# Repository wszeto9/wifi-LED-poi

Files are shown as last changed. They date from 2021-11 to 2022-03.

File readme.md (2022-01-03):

# WiFi-LED-Poi
USB-C Rechargable, WiFi Capable Glow Poi

<h2> Features:</h2>
<ul>
<li>ESP-32 MCU capable of WiFi-communication and syncronization of lights with music</li>
<li>Rechargable battery with a battery life of 3.5-5 hours</li>
<li>Programmable over USB-C</li>
<li>Charging over USB-C</li>
<li>0.47F Supercapacitor capable of nefarious discharge acts</li>
<li>Onboard accelerometer and microphone</li>
</ul>

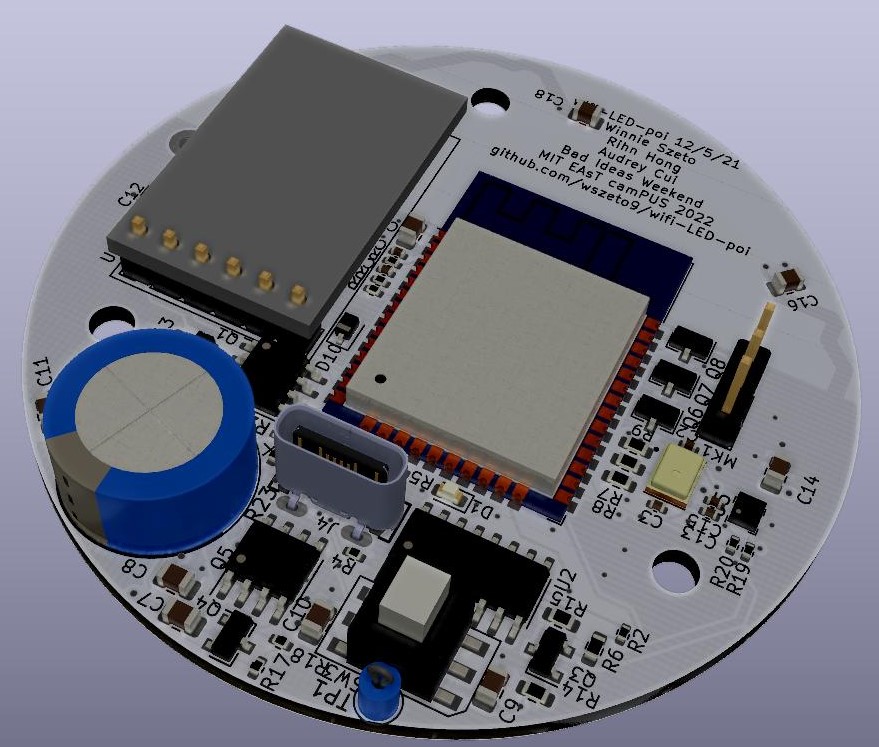
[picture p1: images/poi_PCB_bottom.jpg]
BOTTOM

PCB Bottom

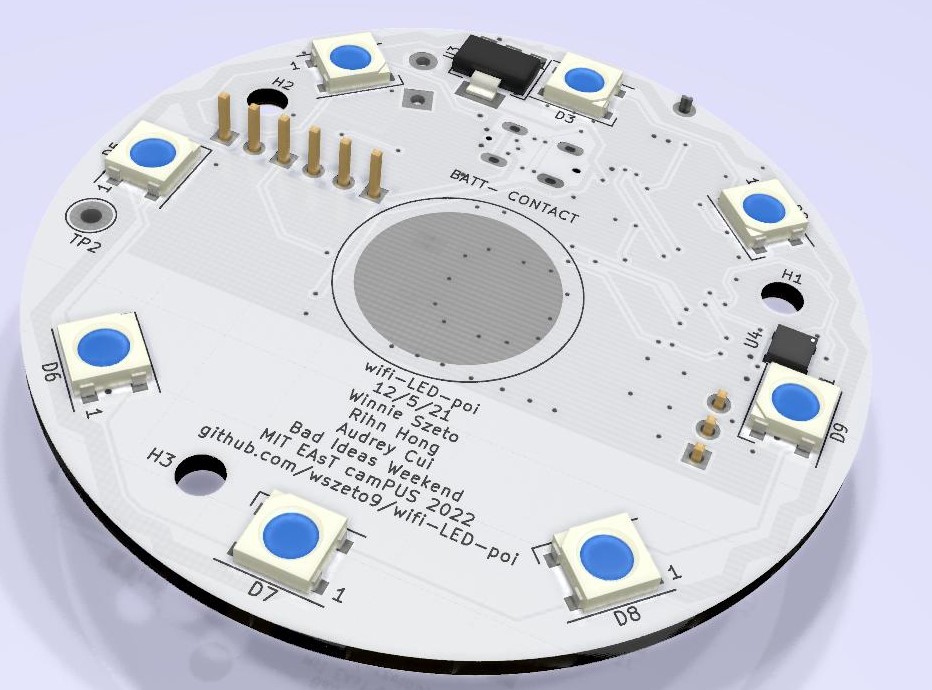
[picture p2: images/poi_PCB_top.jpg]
TOP

PCB Top

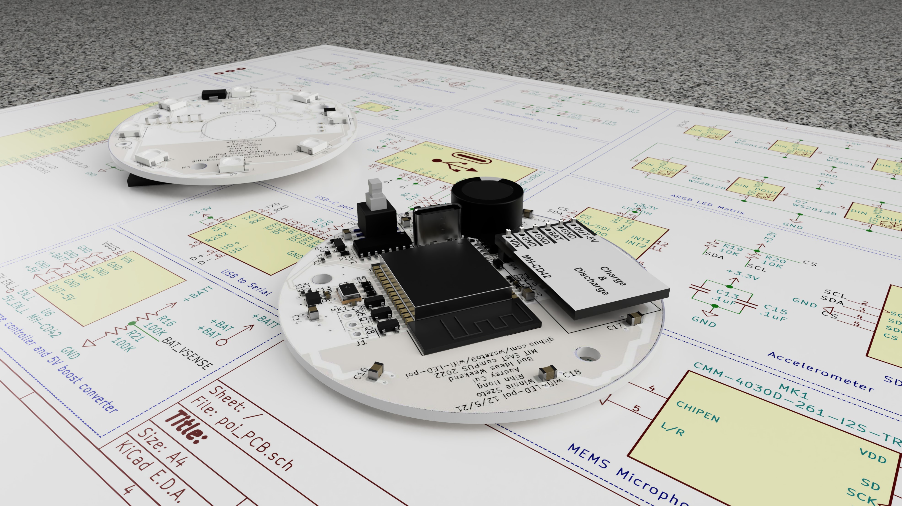
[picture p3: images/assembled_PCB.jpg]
3D assembled

PCBA

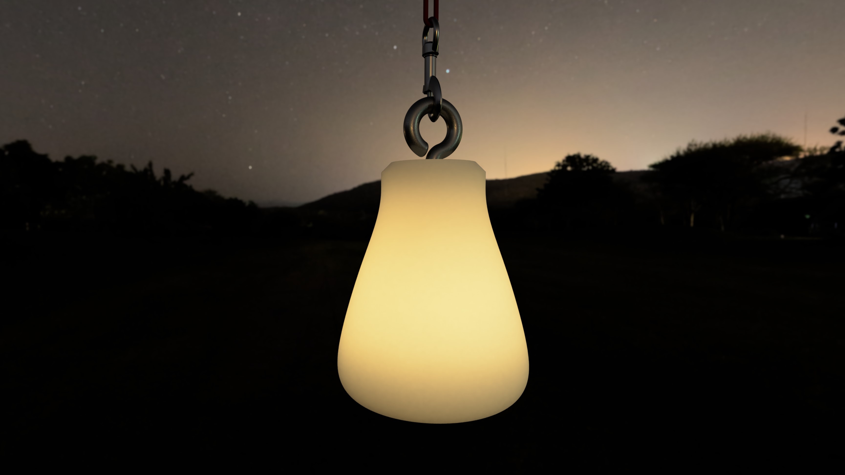
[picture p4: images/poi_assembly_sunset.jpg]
animation

Glow Poi assembled with shell and battery

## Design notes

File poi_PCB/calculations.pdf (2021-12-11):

PCB Layout
Component placement (LEDs, mounting holes)

led_coords = 8×2
125.1777 95.1777
107.5000 102.5000
89.8223 | 95.1777
82.5000 | 77.5000
89.8223 | 59.8223
107.5000 | 52.5000
125.1777 | 59.8223
132.5000 | 77.5000
mountingHolePos = 1×2
129.0711 66.9791
mountingHolePos = 1×2
86.1158 66.6042
mountingHolePos = 1×2
100.0836 100.3254

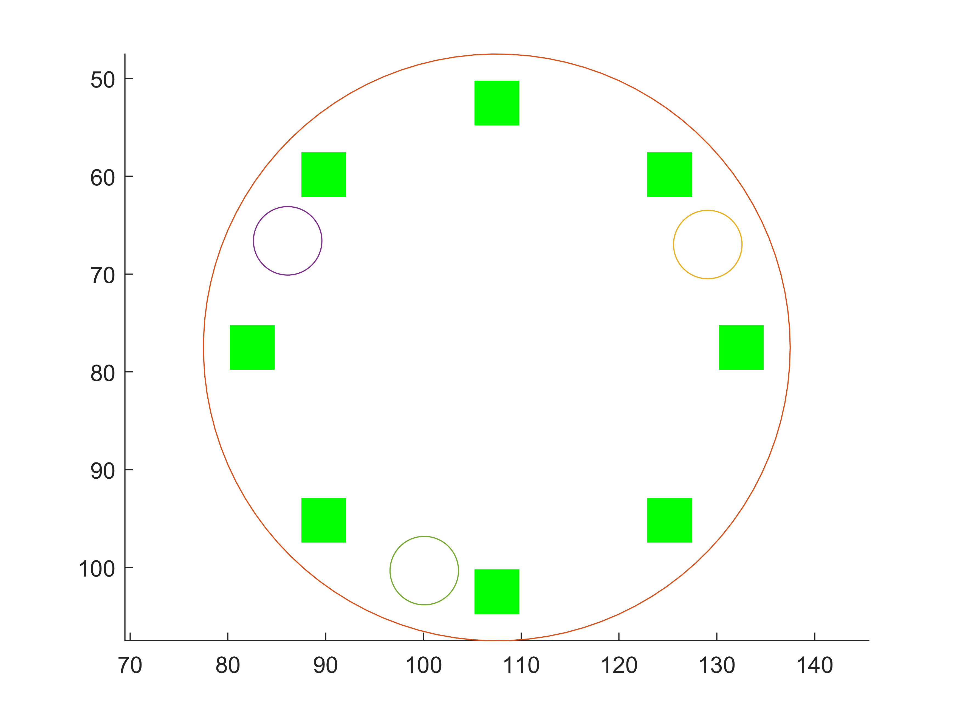
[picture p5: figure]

Calculate position of capacitor for .POS file exporting (KiCAD will not put the positions of through hole components, so the capacitor must be interpolated from nearby component data)

cap_pos_x = -11.3435
cap_pos_y = 17.1943

Component choices

Checking the behavior of C4 (Supercapacitor) and R1 (Shield resistor). Results suggest using PWM to adjust the charging voltage of C4, as suggested below. Suggested charging curve of

where t is in seconds.

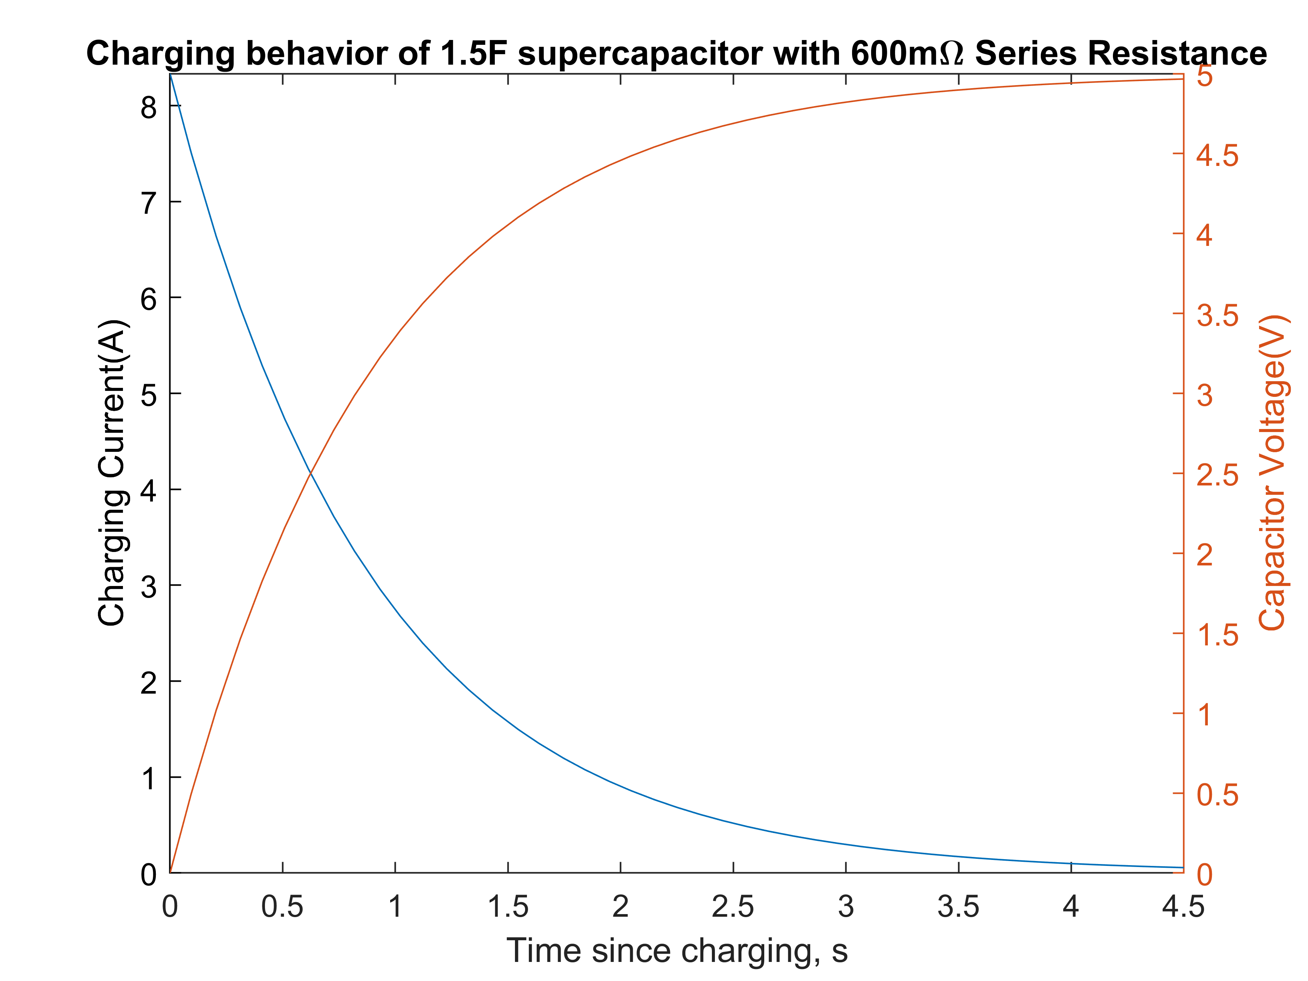
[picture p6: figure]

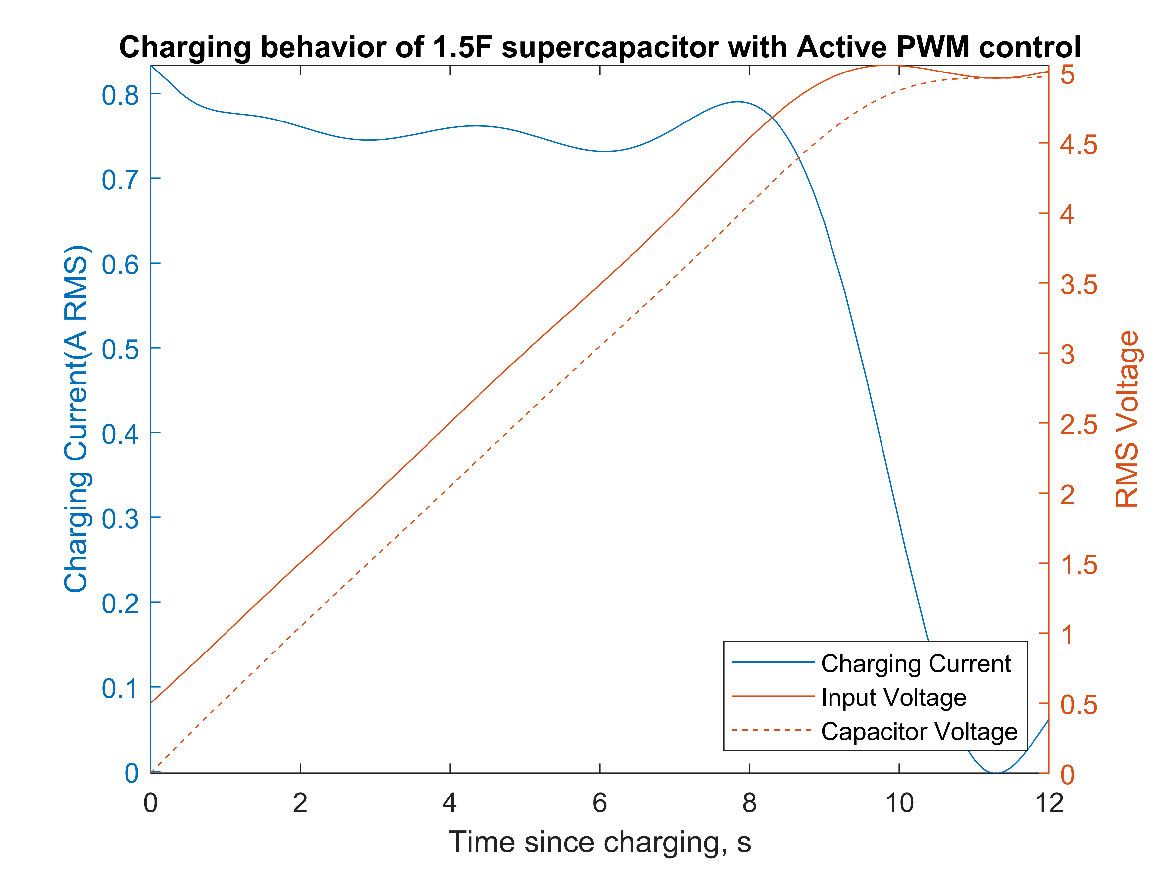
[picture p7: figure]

temperature_increase_of_steel_wool_after_discharge = R_shield = 500
drain_tau = 12.5000
max_power_shield_resistor = 0.0500 resistance_value_ok = logical
1

Battery life calculations

energy_per_capacitor_charge =

battery_life =

battery_life_loss_one_capacitor_discharge =

Checking delay RC circuits on the reset pin

enable_delay_time_ms = 14.1414

Calculations for the acceleration that is measured by the accelerometer while spinning

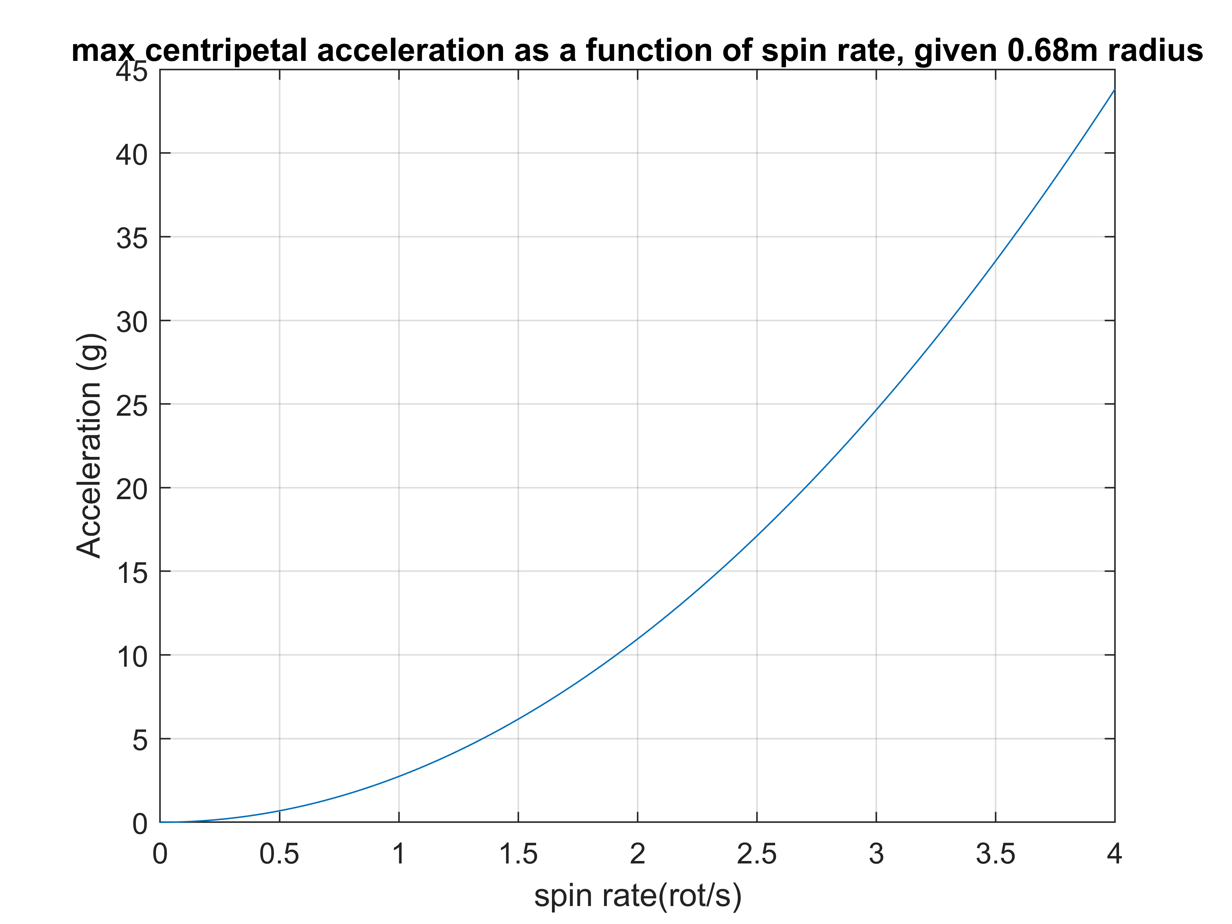
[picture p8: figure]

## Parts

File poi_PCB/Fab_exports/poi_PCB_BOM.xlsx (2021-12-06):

Comment | Designator | Footprint | LCSC
.1uF | C2,C13,C15 | Capacitor_SMD:C_0402_1005Metric | C1546
220pF | C3 | Capacitor_SMD:C_0402_1005Metric | C1530
0.47F | C4 | Capacitor_THT:CP_Radial_D13.0mm_P5.00mm | C239004
10uF | C5,C7,C8,C9,C10,C11,C12,C14,C16,C17,C18 | Capacitor_SMD:C_0805_2012Metric | C15850
100nF | C1,C6 | Capacitor_SMD:C_0402_1005Metric | C307331
LED | D1 | LED_SMD:LED_0603_1608Metric | C2290
1N5819WS | D10 | Diode_SMD:D_SOD-323 | C191023
LIS2DH | U5 | Package_LGA:LGA-12_2x2mm_P0.5mm | C110926
AO3400A | Q2,Q3,Q4,Q6,Q7,Q8 | Package_TO_SOT_SMD:SOT-23 | C20917
AO4407C | Q1,Q5 | Package_SO:SOIC-8_3.9x4.9mm_P1.27mm | C20897
1K | R1 | Resistor_SMD:R_0402_1005Metric | C25744
10K | R10,R11,R13,R17,R18,R19,R20 | Resistor_SMD:R_0402_1005Metric | C25744
10K | R6,R14,R15 | Resistor_SMD:R_0603_1608Metric | C25804
220 | R2 | Resistor_SMD:R_0402_1005Metric | C25091
100K | R16,R21,R22,R23 | Resistor_SMD:R_0402_1005Metric | C25741
5.1K | R3,R4 | Resistor_SMD:R_0402_1005Metric | C25905
220R | R5 | Resistor_SMD:R_0402_1005Metric | C25091
51R | R7,R8,R9 | Resistor_SMD:R_0603_1608Metric | C23197

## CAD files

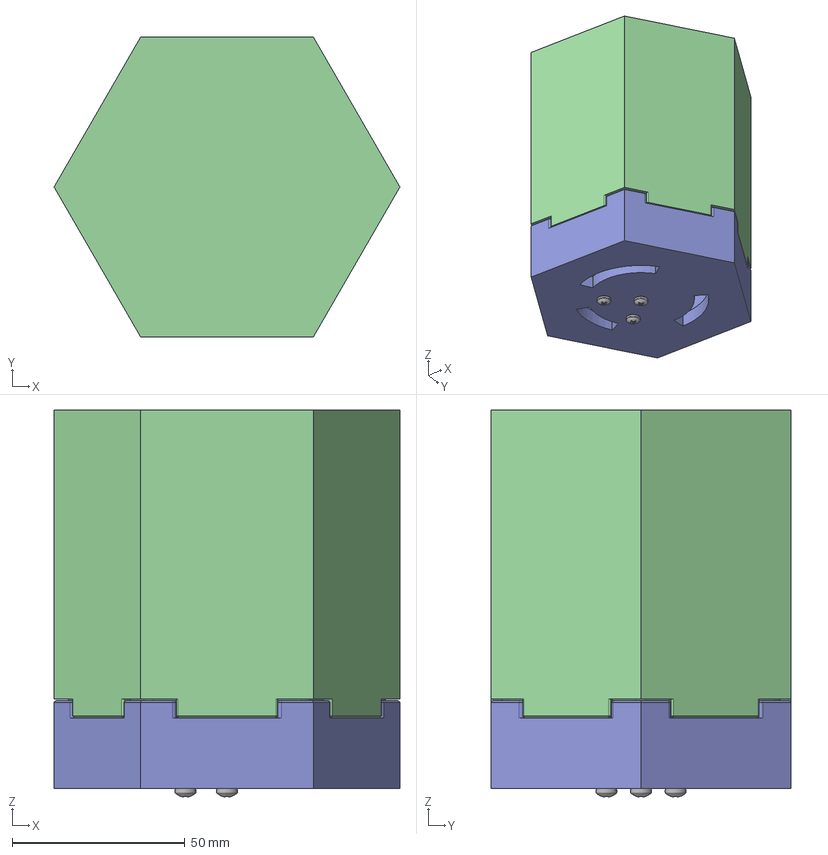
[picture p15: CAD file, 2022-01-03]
manufacturing/CAD files/mold_assembly.step
100.0 x 86.6 x 111.9 mm
mold_inside_A
mold_inside_B
mold_bottom_outer
mold_top_outer
F1-B-M3-Heatfit x 6
92000A122_Passivated 18-8 Stainless Steel Pan Head Phillips Screws x 6

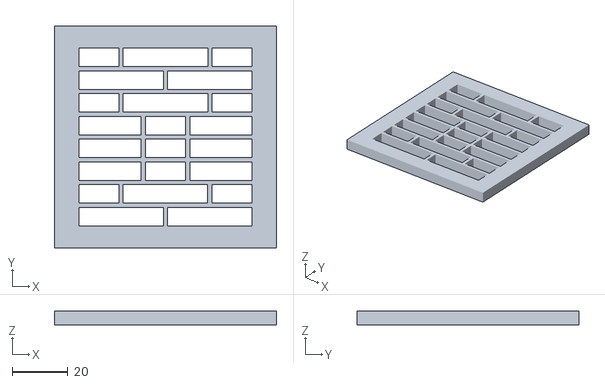
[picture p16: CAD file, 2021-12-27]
code/PlatformIO/WLED-master/usermods/word-clock-matrix/Word Clock Baffle.stl
80.0 x 80.0 x 5.00

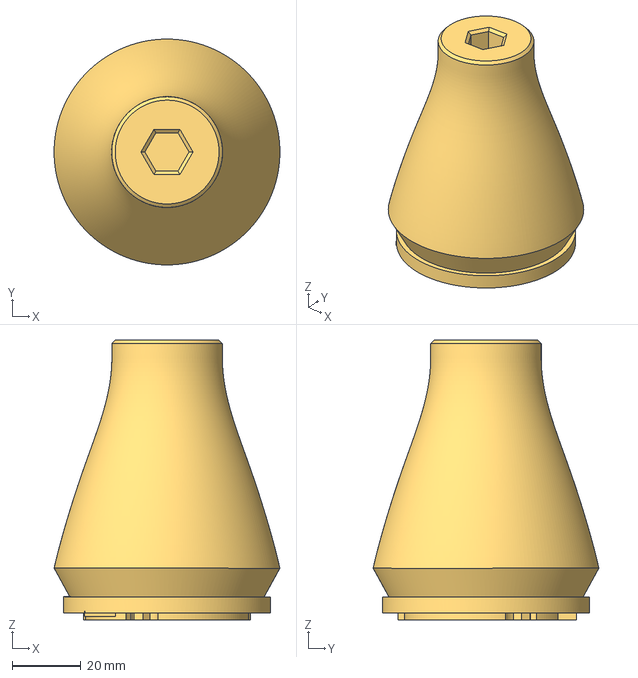
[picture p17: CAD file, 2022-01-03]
manufacturing/3D print/mold_inside_piece_A.3mf
65.5 x 65.5 x 81.3 mm

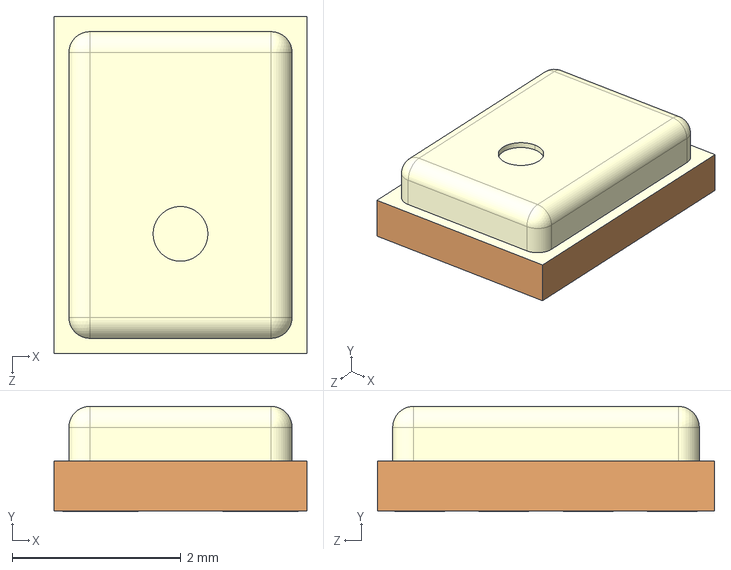
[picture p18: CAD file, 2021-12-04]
poi_PCB/Packages/CMM-4030D-261-I2S-TR/CUI_DEVICES_CMM-4030D-261-I2S-TR.step
3.00 x 1.25 x 4.00 mm

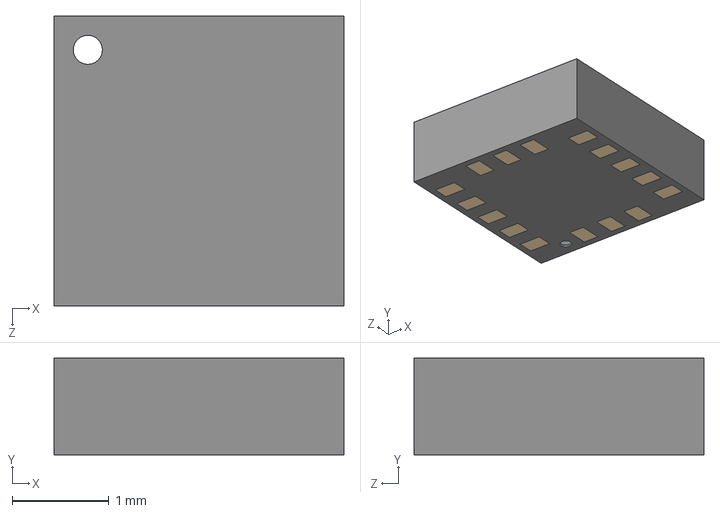
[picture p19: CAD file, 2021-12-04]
poi_PCB/Packages/LSM6DS33TR/LSM6DS33TR.step
3.00 x 1.00 x 3.00 mm

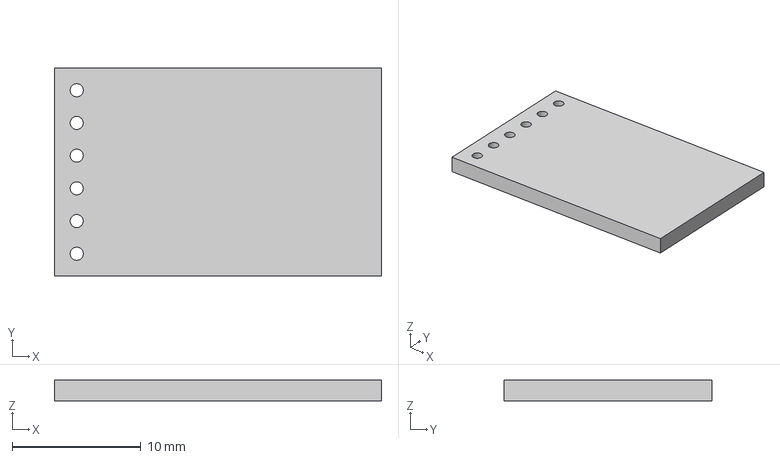
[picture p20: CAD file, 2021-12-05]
poi_PCB/Packages/MH-CD42.step
25.4 x 16.2 x 1.60 mm

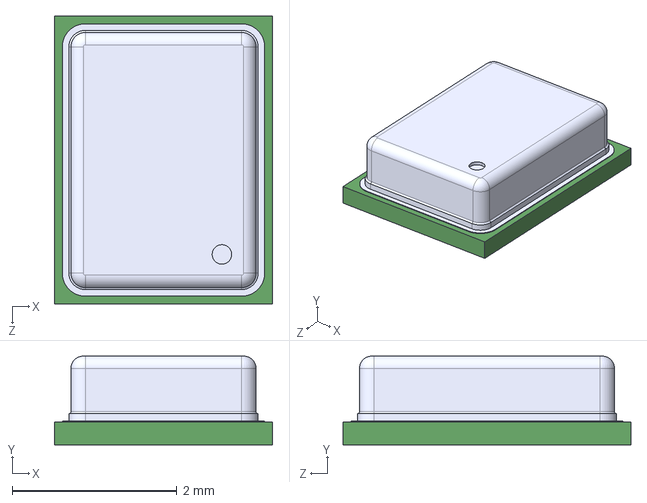
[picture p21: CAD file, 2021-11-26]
poi_PCB/Packages/SPH0645LM4H-B/SPH0645LM4H-B.step
2.65 x 1.08 x 3.50 mm

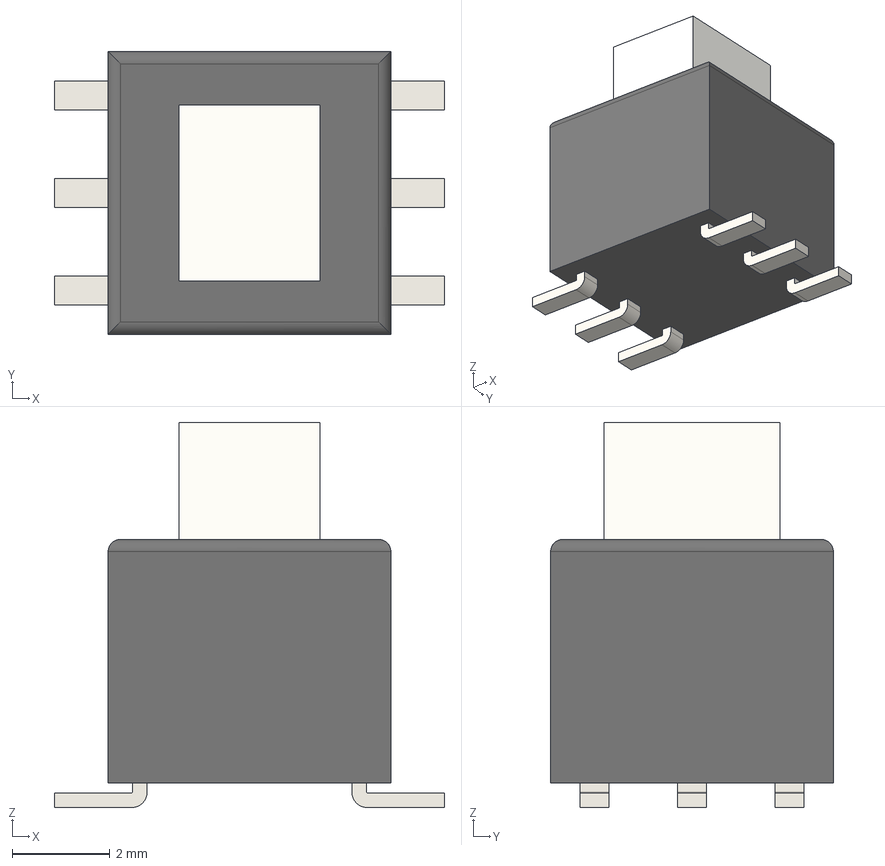
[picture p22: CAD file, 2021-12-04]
poi_PCB/Packages/TL2233OA/TL2233OA.step
8.00 x 5.80 x 7.90 mm

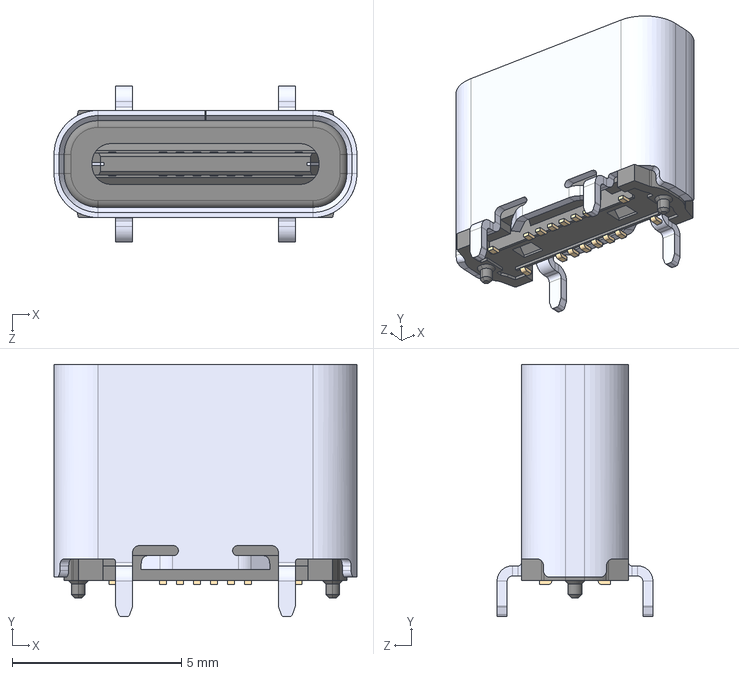
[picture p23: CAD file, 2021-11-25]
poi_PCB/Packages/USB4120-03-C_REVA/USB4120-03-C_REVA.step
8.94 x 7.45 x 4.60 mm

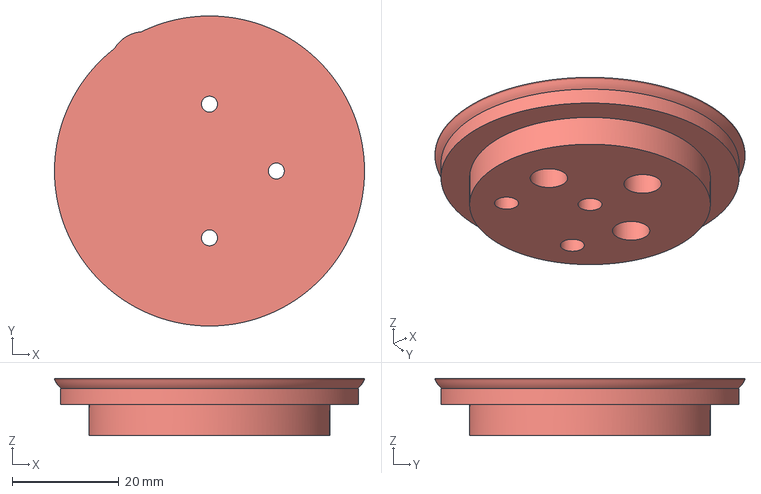
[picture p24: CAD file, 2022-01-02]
manufacturing/3D print/mold_inside_piece_B.3mf
58.0 x 58.0 x 10.7 mm

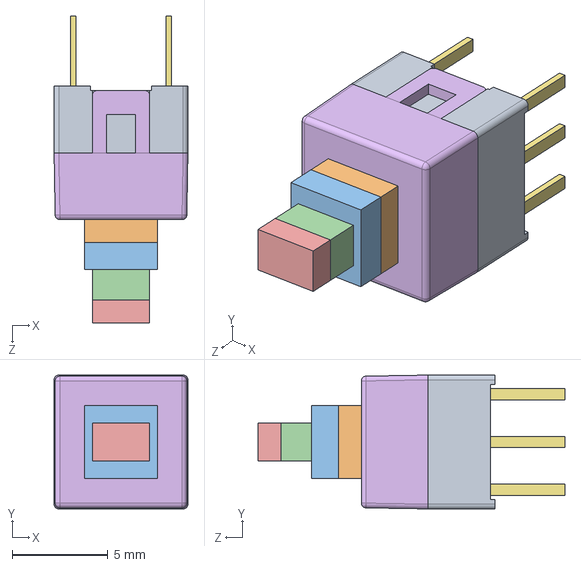
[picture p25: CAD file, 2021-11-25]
poi_PCB/Packages/LatchSwitch_7x7.STEP
7.00 x 7.00 x 16.1 mm

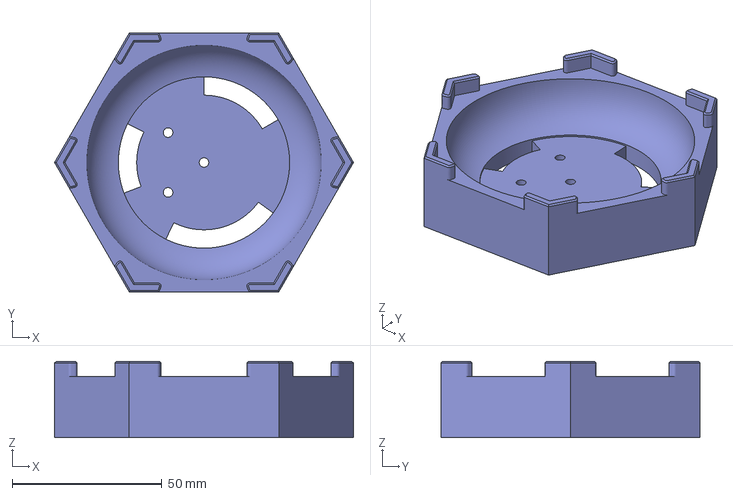
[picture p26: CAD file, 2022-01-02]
manufacturing/3D print/mold_bottom_outer.3mf
100.0 x 86.6 x 25.4 mm

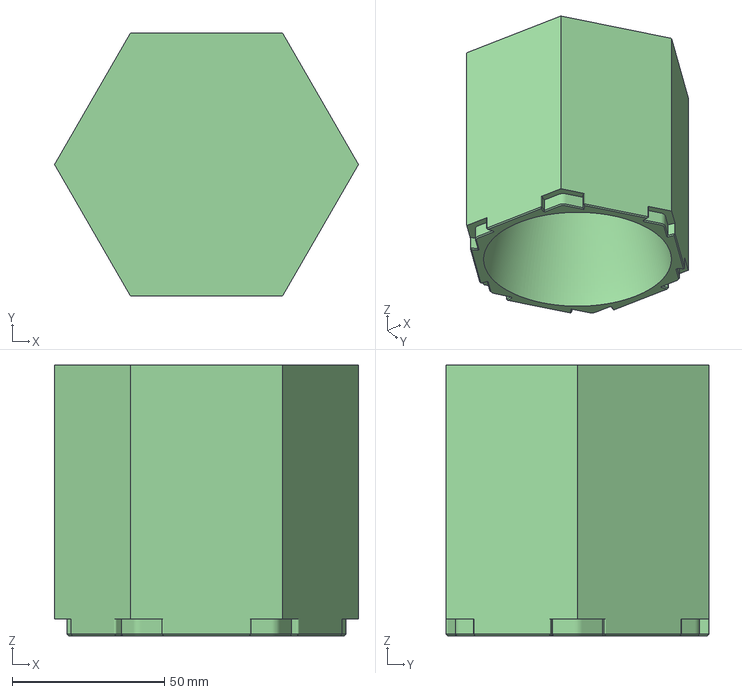
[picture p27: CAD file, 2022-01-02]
manufacturing/3D print/mold_top_outer_mold.3mf
100.0 x 86.6 x 89.0 mm

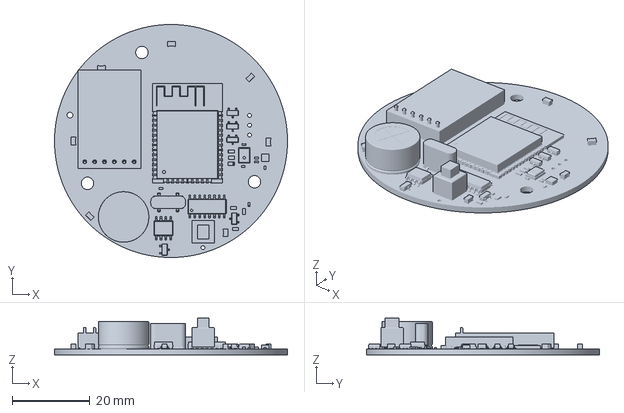
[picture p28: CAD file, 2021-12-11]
manufacturing/3D print/[OPTIONAL]PCB_scale_model.3mf
60.0 x 60.0 x 9.45 mm

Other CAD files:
manufacturing/3D print/PCB_spacer.3mf
manufacturing/3D print/outer_cover.3mf
manufacturing/3D print/bottom_batt_support.3mf

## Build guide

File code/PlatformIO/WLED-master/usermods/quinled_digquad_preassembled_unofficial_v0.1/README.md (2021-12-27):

# QuinLED-Dig-Quad Preassembled Unofficial Build

This usermod targets the [Preassembled QuinLED-Dig-Quad](https://quinled.info/pre-assembled-quinled-dig-quad/). Tested on board revision v1r6b,
and includes the following features:

 * **Multi-channel Support** - enabling use of LED1, LED2, LED3, LED4 pins to work using segments
 * **Temperature Sensor Support** - pulls readings from the built-in temperature sensor and adds the reading to the *Info* page in the UI

## Background

As a starting point, you should check out this awesome video from Quindor: [How to compile WLED yourself](https://quinled.info/2020/12/22/livestream-wled-compile/). The usermod you are reading now just provides some shortcuts for parts of what were covered in that video.

## Build Firmware with Multi-channel and Temp Support

1. Copy the `platformio_override.ini` file to the project's root directory
1. If using VS Code with the PlatformIO plugin like in the video, you will now see this new project task listed in the PLATFORMIO panel at the bottom as `env:QL-DigQuad-Pre-v0.1` (you probably need to hit the refresh button) 

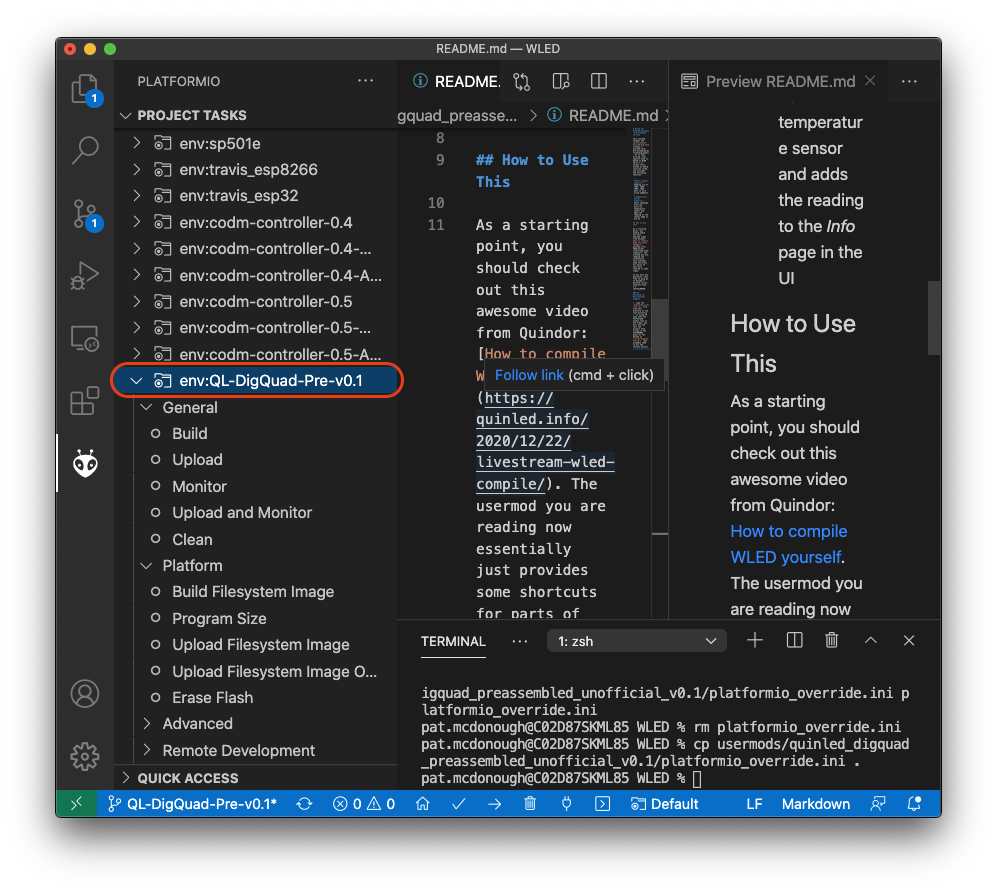
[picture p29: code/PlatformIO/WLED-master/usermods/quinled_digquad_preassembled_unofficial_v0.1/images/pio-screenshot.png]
   

1. Edit this file from the root directory as needed:

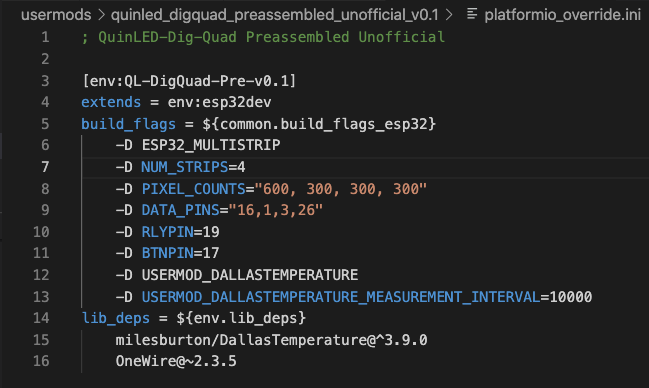
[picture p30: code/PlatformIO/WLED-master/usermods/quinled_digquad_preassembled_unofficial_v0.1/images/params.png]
   

   * `PIXEL_COUNTS` may need to be adjusted for your set-up. E.g. I have lots of LEDs in Channel 1, but that's probably unusual for most
   * `DATA_PINS` may need to be changed to "16,3,1,26" instead of "16,1,3,26" apparently depending on the board revision or some such

1. Build the mod (e.g. click `Build` from the project task circled above) and update your firmware using the `QL-DigQuad-Pre-v0.1` file, e.g. using _Manual OTA_ from the Config menu. Based on the video and my own experience, you might need to build twice 🤷‍♂️.

## Observing Temperature

Hopefully you can now see the Temperature listed in the Info page. If not, use Chrome Developer Tools to find the current temperature

1. Open the Developer Tools Console
2. Enter `lastinfo.u.Temperature` to view the Temperature array

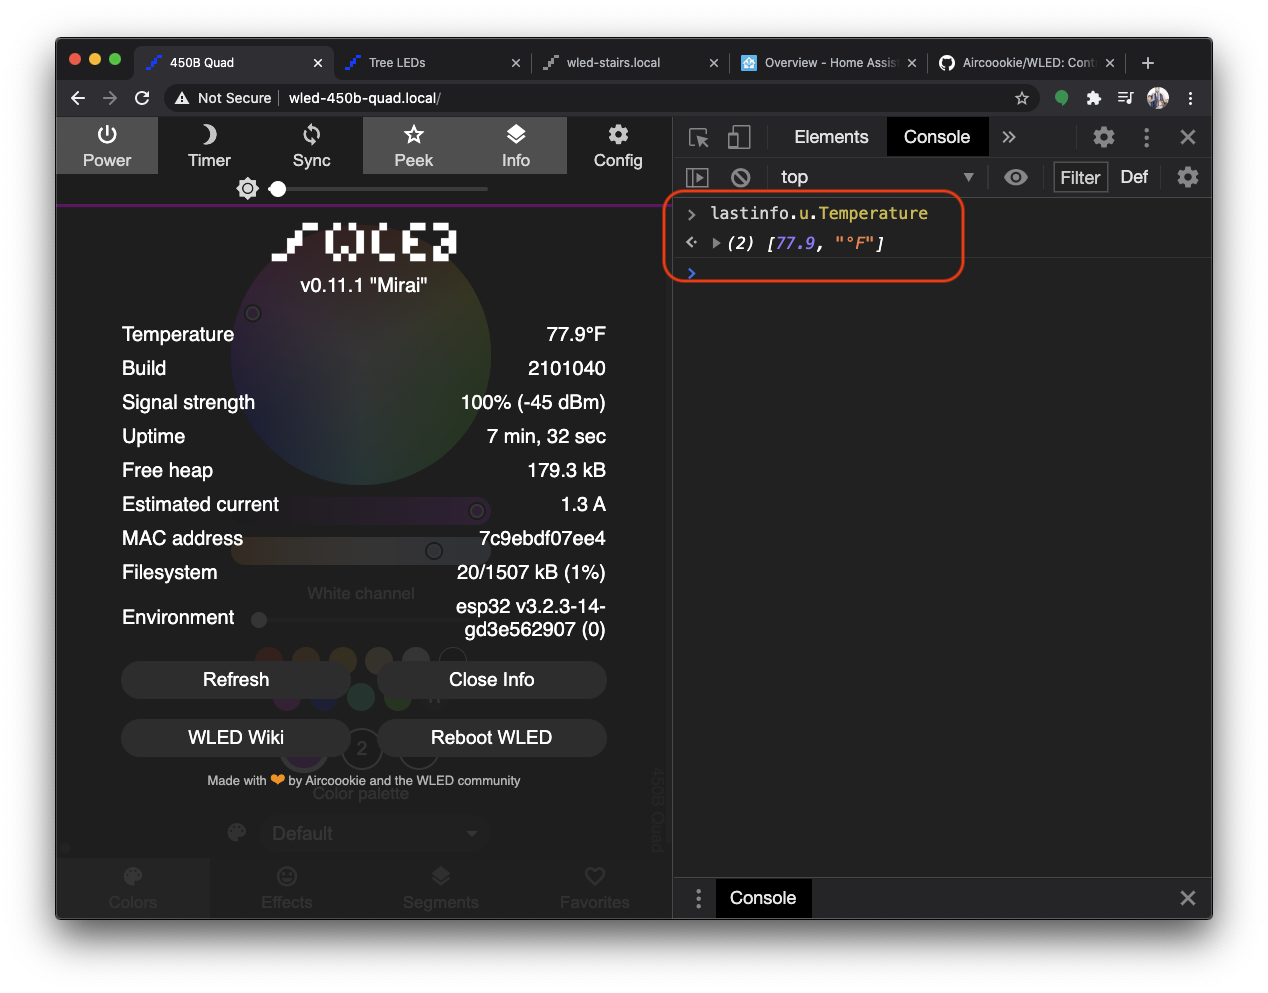
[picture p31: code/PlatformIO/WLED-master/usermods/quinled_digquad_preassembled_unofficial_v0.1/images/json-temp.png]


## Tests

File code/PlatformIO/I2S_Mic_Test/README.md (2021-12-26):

# Microphone test code

<h2> Detects audio volume (in dB) and controls pin 13 (LED brightness) based on volume.</h2>

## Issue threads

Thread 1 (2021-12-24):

GPIO2 pulled up; can't upload code to ESP32

wszeto9, 2021-12-24:
Change LED_SIG_3.3 to another GPIO pin to avoid pulling up GPIO2

wszeto9, 2021-12-26:
Fixed in V1.1

Closed 2021-12-26.

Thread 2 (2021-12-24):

AO3400A footprint incorrect

wszeto9, 2021-12-24:

wszeto9, 2021-12-26:
Fixed in V1.1

Closed 2021-12-26.

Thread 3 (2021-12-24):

10K Pullup resistor on LED_SIG_5 is too large

wszeto9, 2021-12-24:
Mosfet cannot switch fast enough at the speeds needed to send data to the LEDs. Image below represents the response to a step pulse. Rise time is ~5us, which is too long compared to the frequency that the LED data is sent at.
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

Image below is the data sent to the LED. There is not enough time for the resistors to pull the circuit up to 5V.
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

wszeto9, 2021-12-24:
Suggested fix: remove logic level shifter circuit, replace with wire from LED_SIG_3.3 to LED_SIG_5

wszeto9, 2021-12-26:
Fixed in V1.1

Closed 2021-12-26.

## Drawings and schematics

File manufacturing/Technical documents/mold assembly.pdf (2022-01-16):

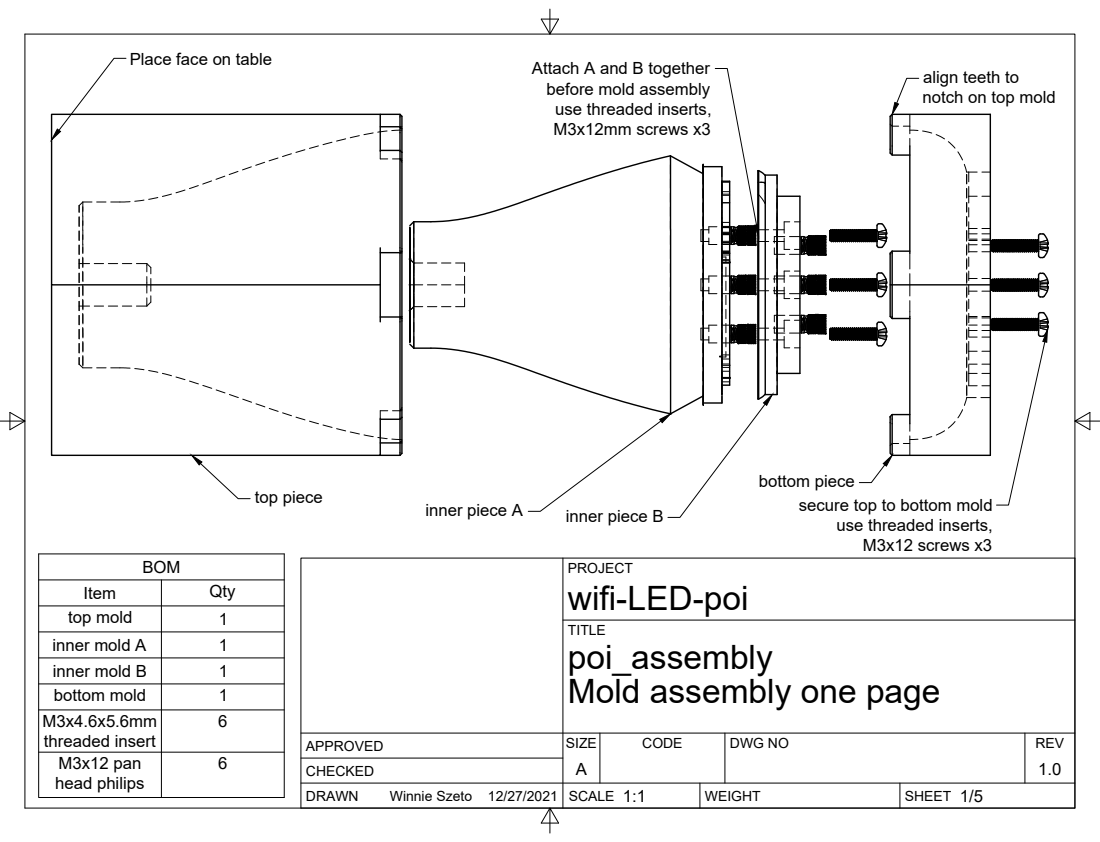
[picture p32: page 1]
SIZE; CODE; DWG NO; REV; Winnie Szeto; top piece; inner piece A; inner piece B; top mold; inner mold A; inner mold B; bottom mold; threaded insert M3x12 pan head philips

Place face on table

Attach A and B together
before mold assembly
use threaded inserts,
M3x12mm screws x3

align teeth to
notch on top mold

bottom piece
secure top to bottom mold
M3x12 screws x3

PROJECT
wifi-LED-poi
poi_assembly
Mold assembly one page

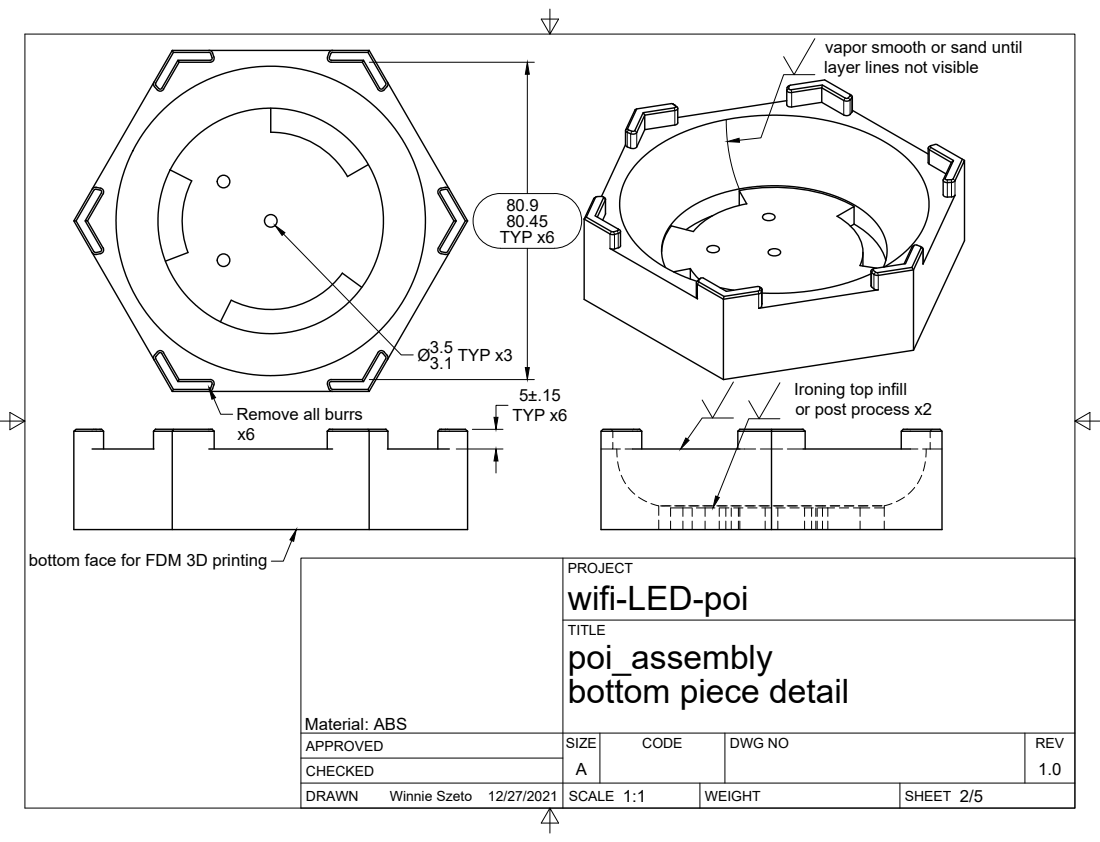
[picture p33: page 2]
SIZE; CODE; DWG NO; REV; Winnie Szeto; TYP x6; 3.1 TYP x3; Remove all burrs; or post process x2; Material: ABS

vapor smooth or sand until
layer lines not visible

Ironing top infill

bottom face for FDM 3D printing

PROJECT
wifi-LED-poi
poi_assembly
bottom piece detail

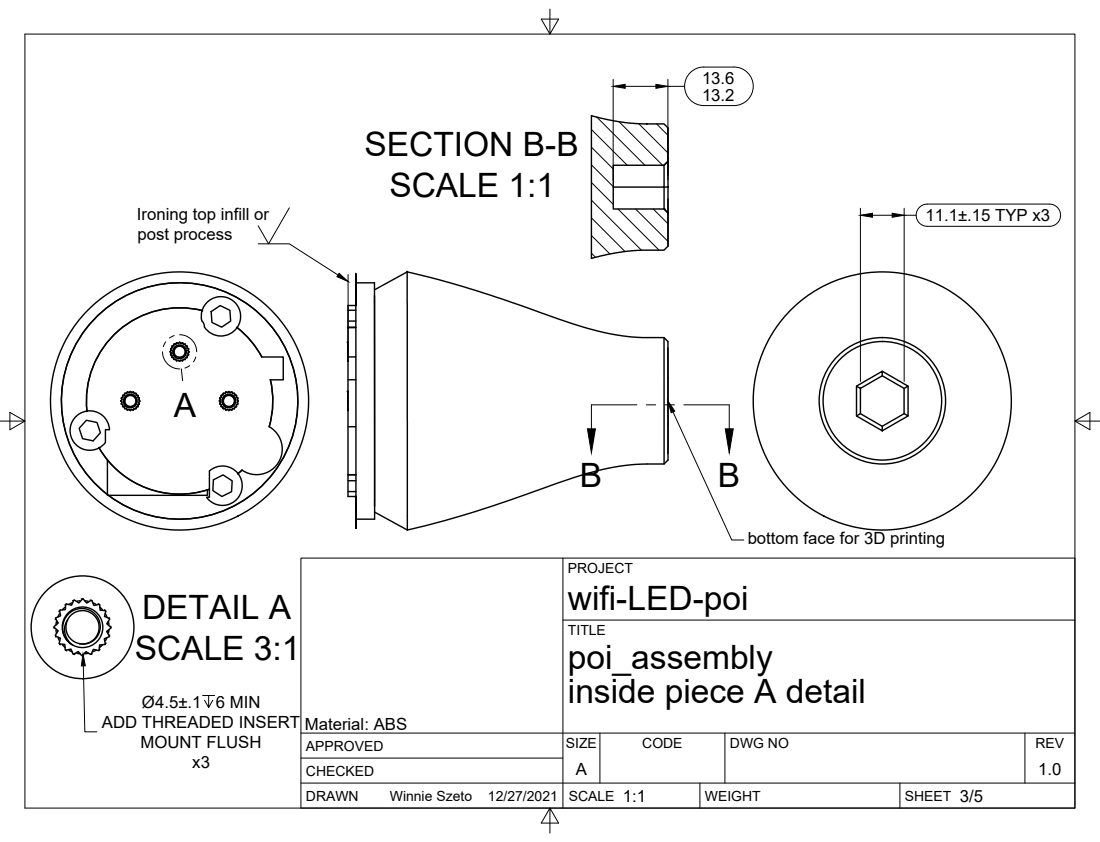
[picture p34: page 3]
SIZE; CODE; DWG NO; REV; Winnie Szeto; DETAIL A SCALE 3:1; 11.1±.15 TYP x3; SECTION B-B SCALE 1:1; Material: ABS

Ironing top infill or
post process

bottom face for 3D printing

PROJECT
wifi-LED-poi
poi_assembly
inside piece A detail

Ø4.5±.1 6 MIN
ADD THREADED INSERT
MOUNT FLUSH

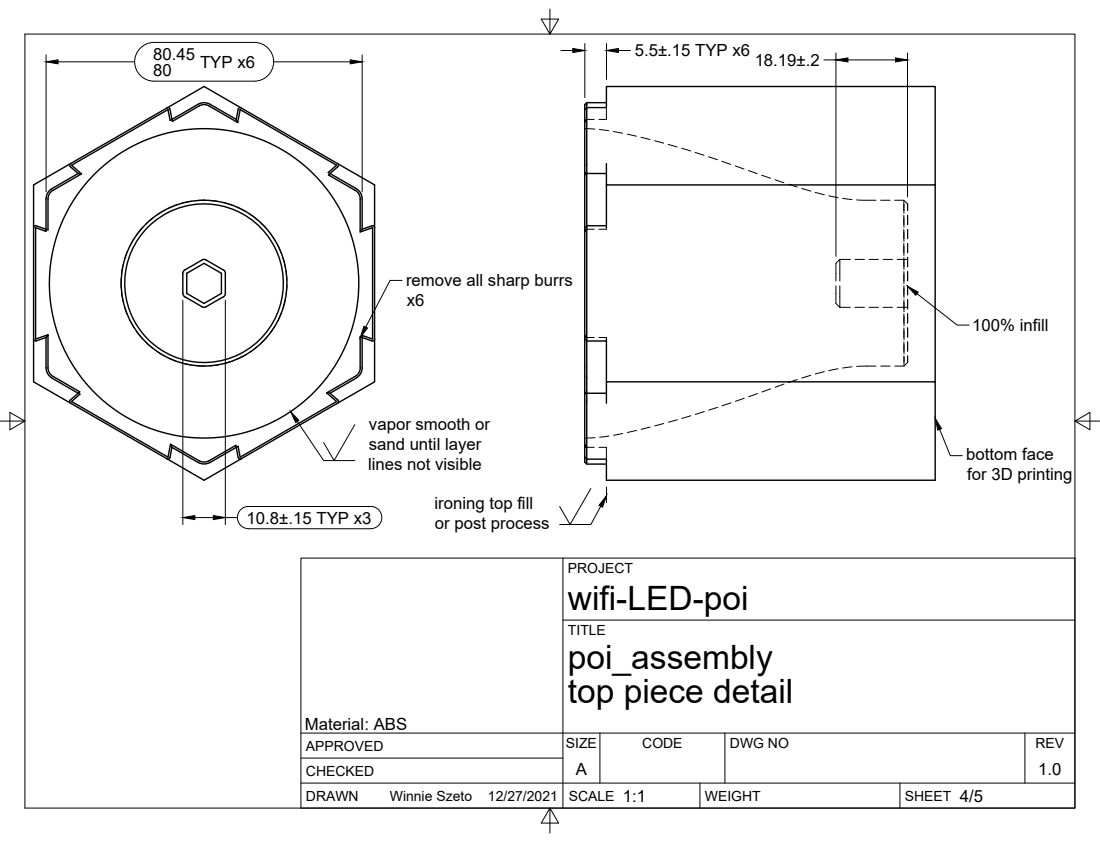
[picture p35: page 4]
SIZE; CODE; DWG NO; REV; Winnie Szeto; 10.8±.15 TYP x3; TYP x6; 5.5±.15 TYP x6; Material: ABS; bottom face for 3D printing; 100% infill

remove all sharp burrs

vapor smooth or
sand until layer
lines not visible

ironing top fill
or post process

PROJECT
wifi-LED-poi
poi_assembly
top piece detail

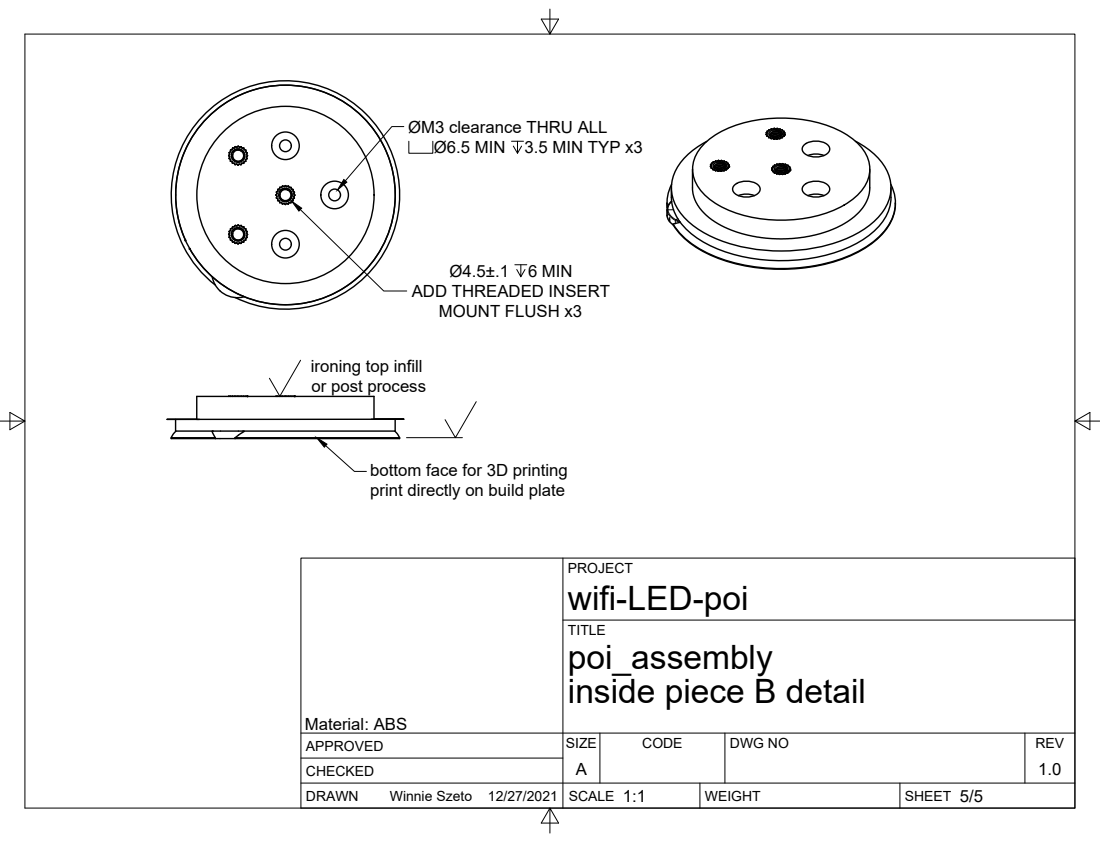
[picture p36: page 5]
SIZE; CODE; DWG NO; REV; Winnie Szeto; Ø6.5 MIN; 3.5 MIN TYP x3; 6 MIN; Material: ABS

ØM3 clearance THRU ALL

ADD THREADED INSERT
MOUNT FLUSH x3

ironing top infill
or post process

bottom face for 3D printing
print directly on build plate

PROJECT
wifi-LED-poi
poi_assembly
inside piece B detail

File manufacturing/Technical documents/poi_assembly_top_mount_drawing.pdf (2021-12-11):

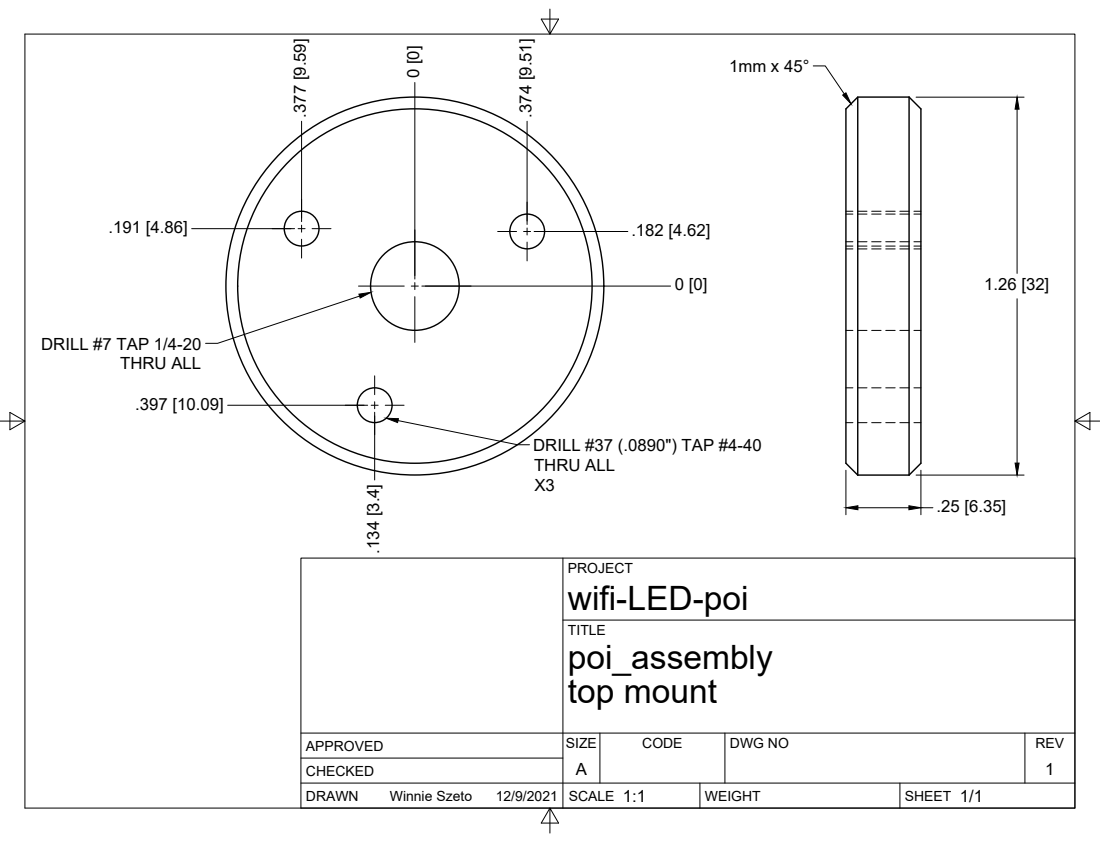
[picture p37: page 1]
SIZE; CODE; DWG NO; REV; Winnie Szeto; DRILL #37 (.0890") TAP #4-40 THRU ALL; DRILL #7 TAP 1/4-20 THRU ALL

PROJECT
wifi-LED-poi
poi_assembly
top mount

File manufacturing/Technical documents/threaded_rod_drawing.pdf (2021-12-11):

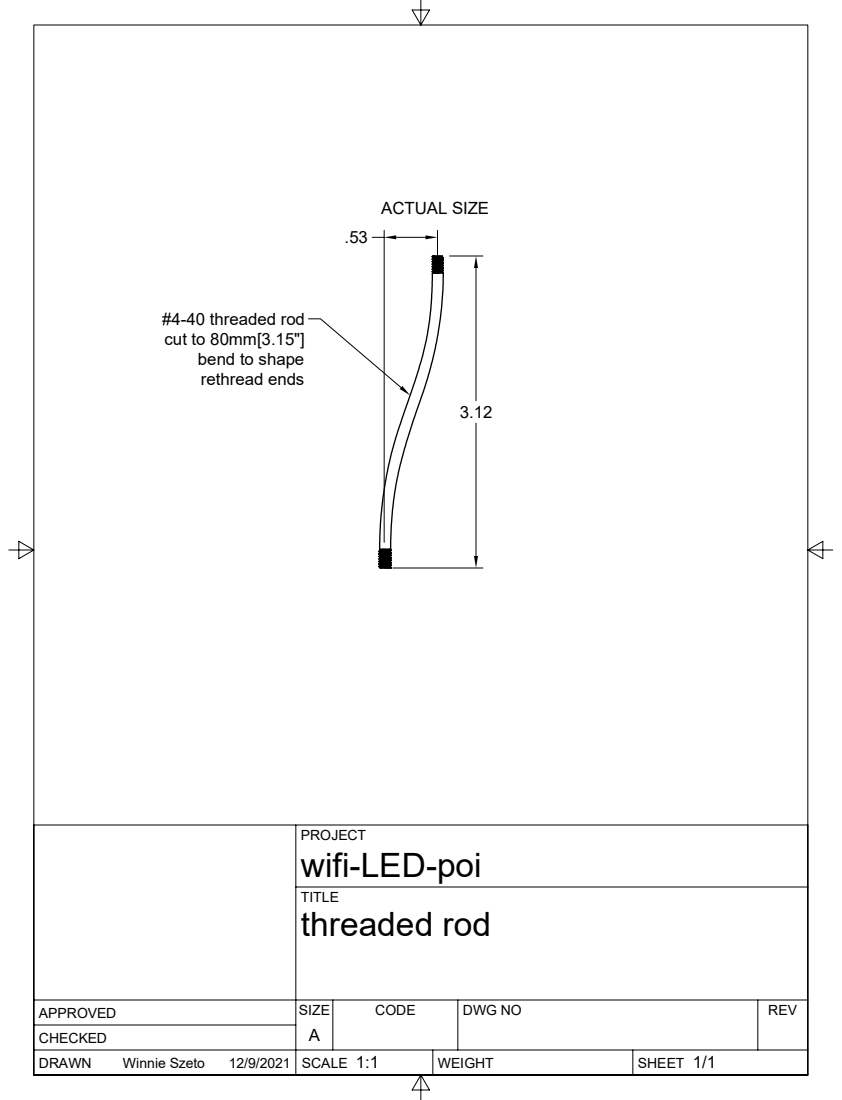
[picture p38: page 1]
TITLE; DRAWN; CHECKED; APPROVED; SCALE; WEIGHT; SHEET; SIZE; CODE; DWG NO; REV; Winnie Szeto; ACTUAL SIZE

#4-40 threaded rod
cut to 80mm[3.15"]
bend to shape
rethread ends

PROJECT
wifi-LED-poi
threaded rod

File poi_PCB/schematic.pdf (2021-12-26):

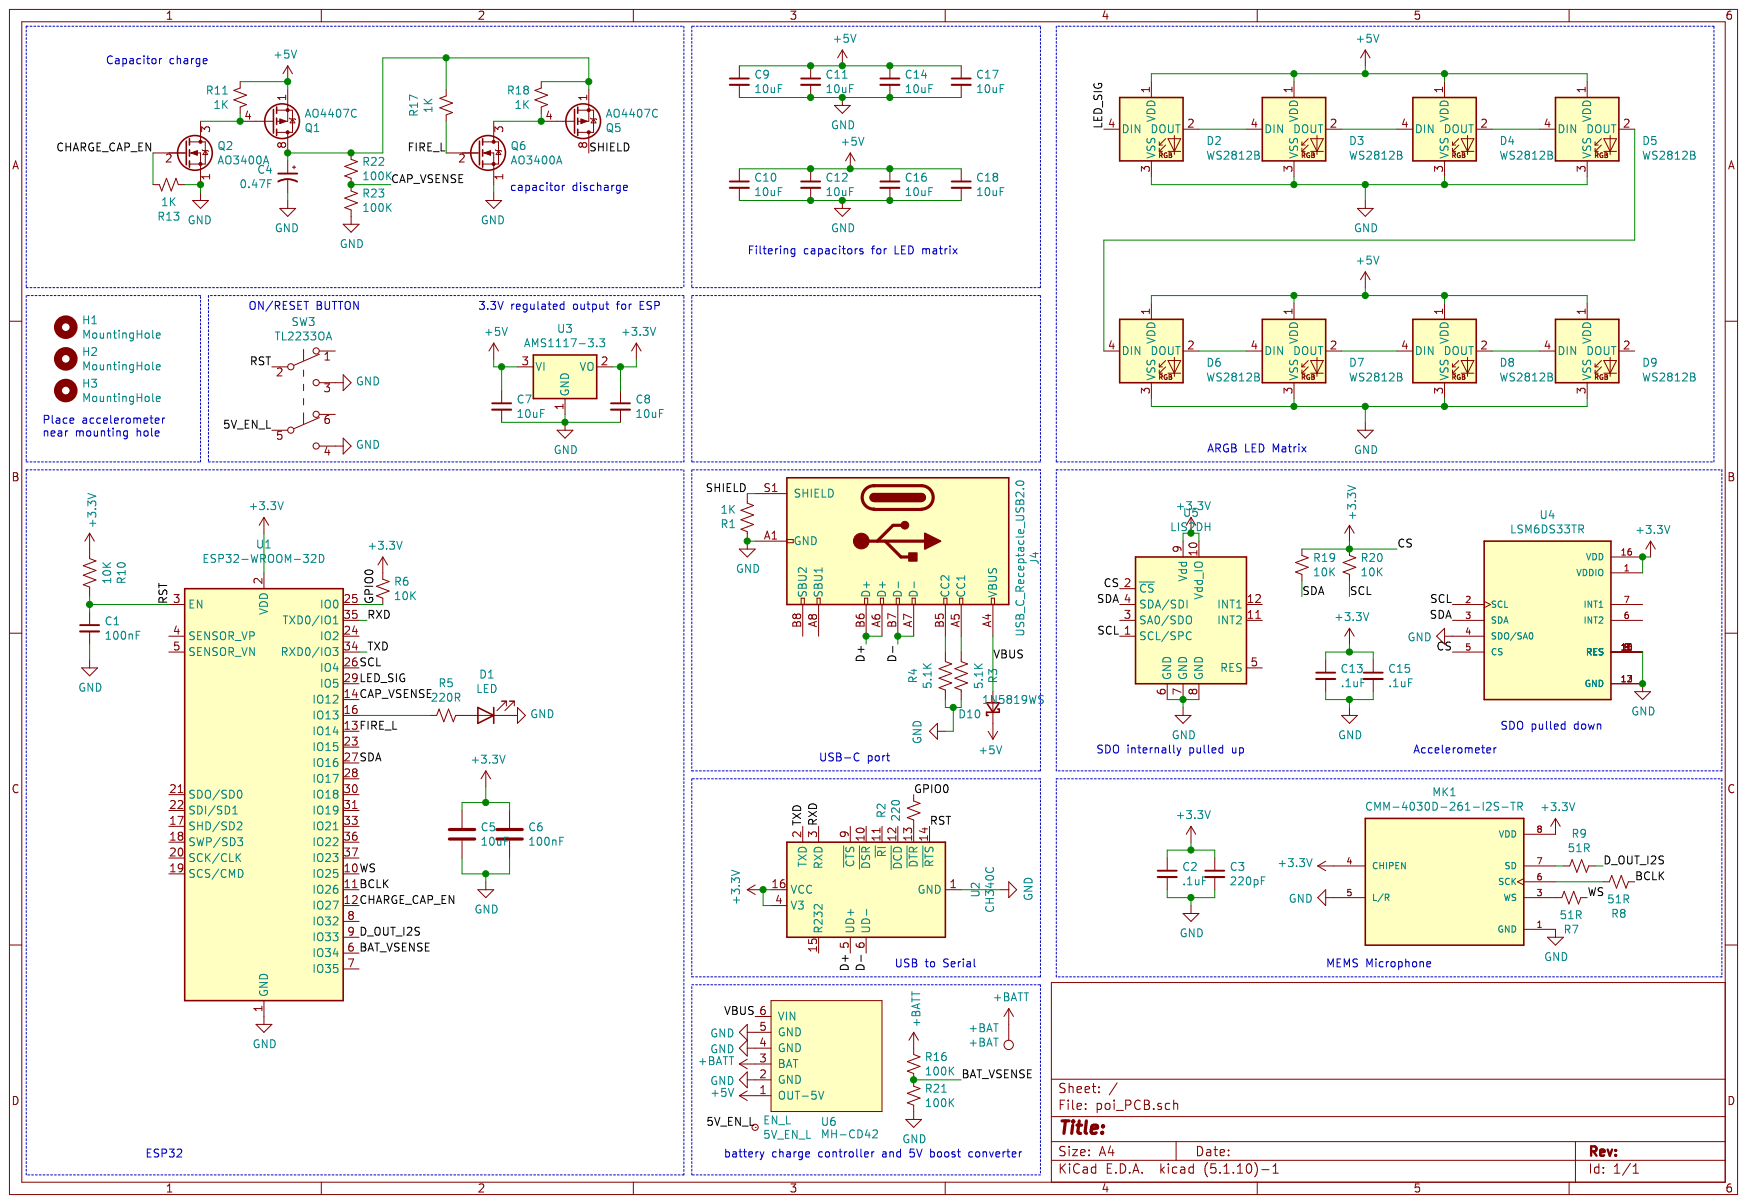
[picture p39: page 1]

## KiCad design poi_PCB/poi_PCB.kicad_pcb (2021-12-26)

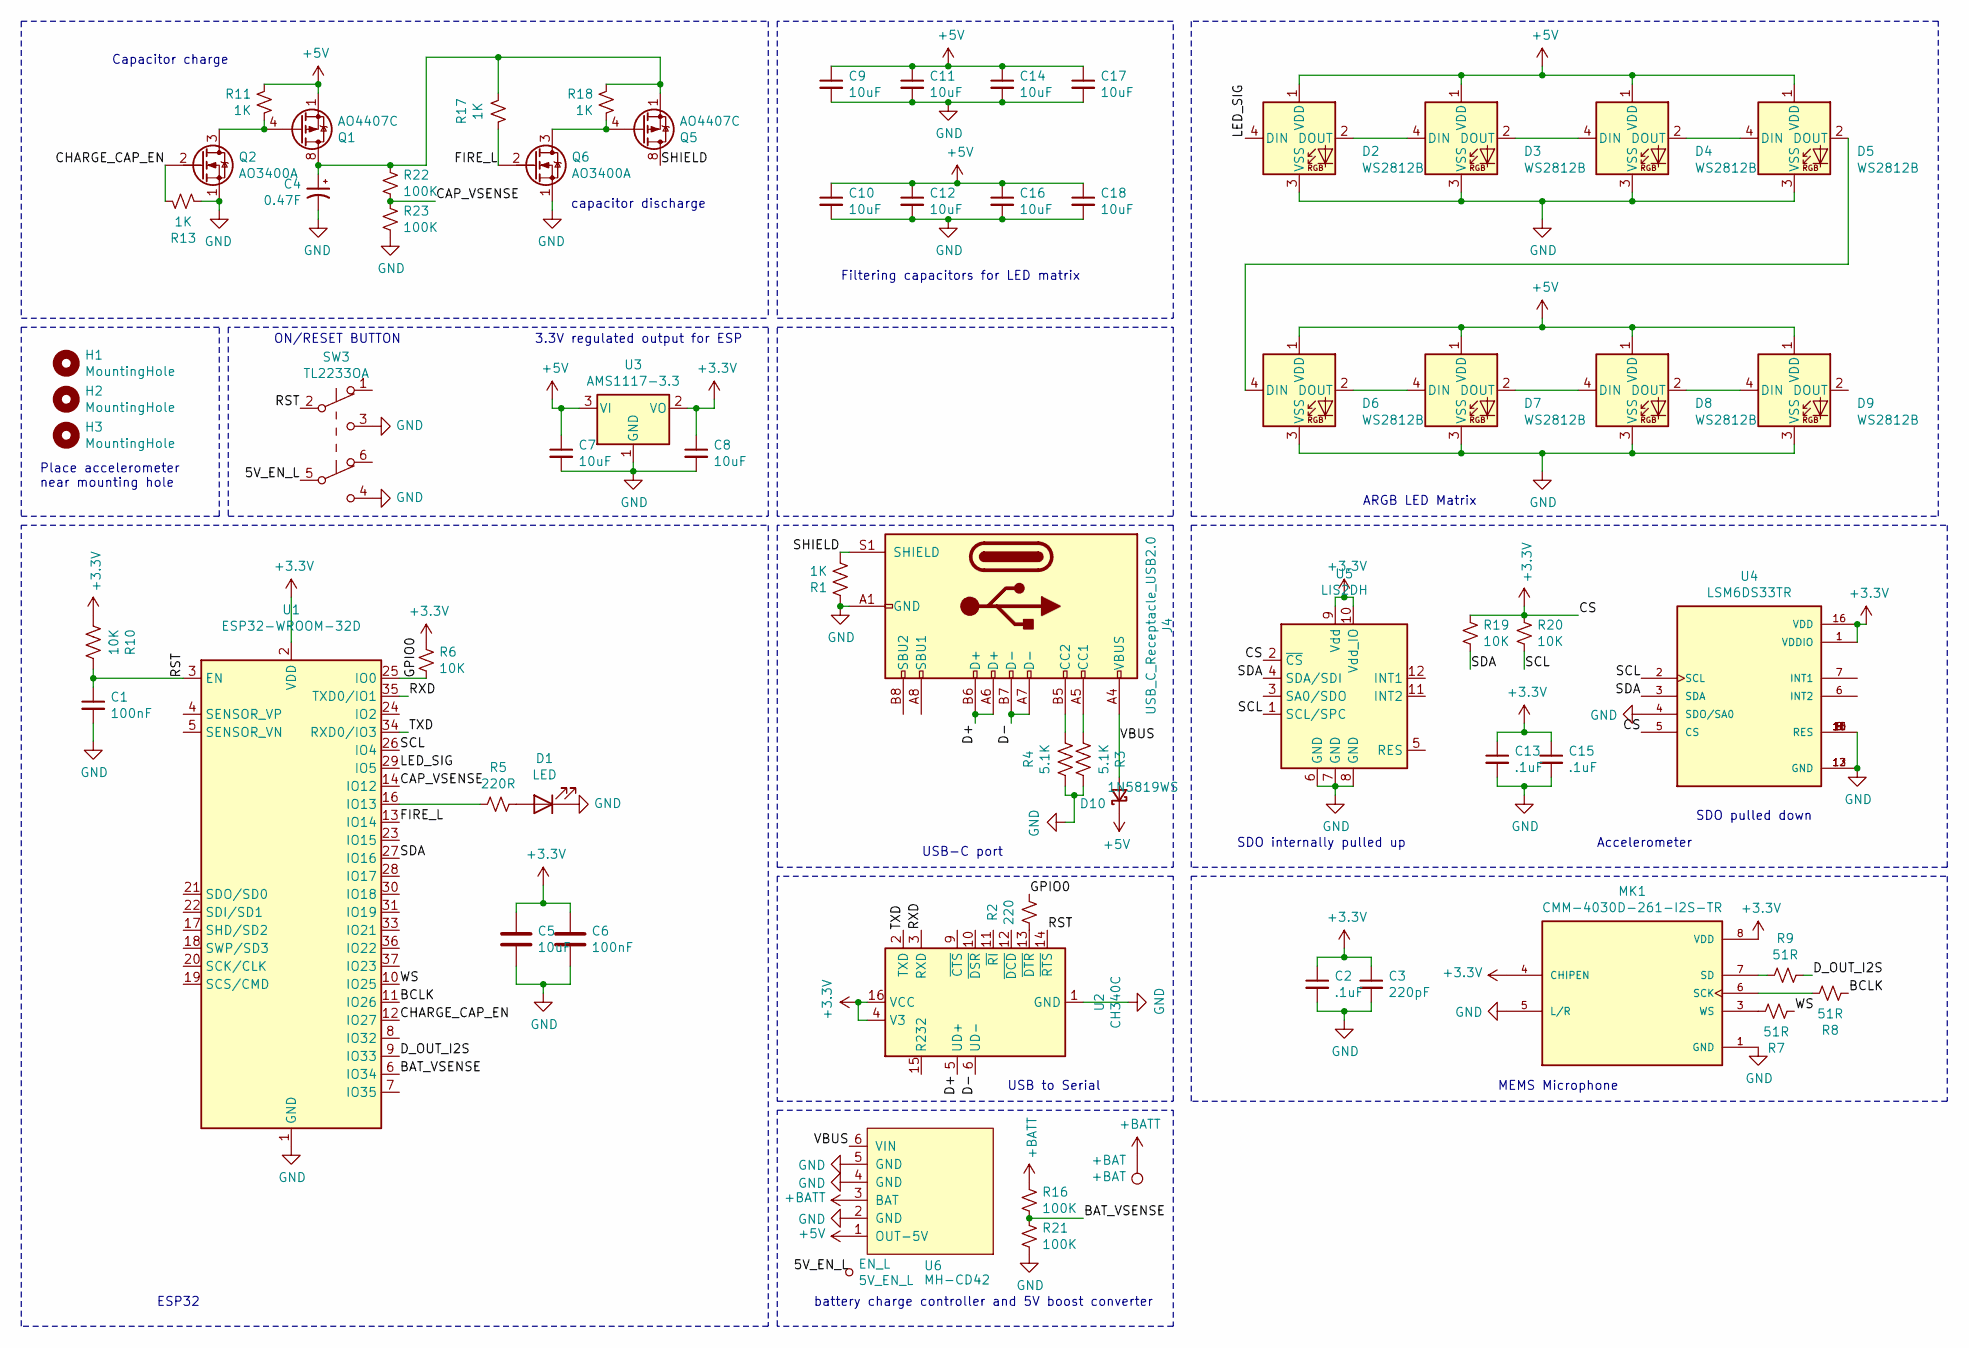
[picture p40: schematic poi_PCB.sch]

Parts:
+BAT: +BAT; TestPoint_THTPad_D3.0mm_Drill1.5mm
C1, C6: 100nF; C_0402_1005Metric; LCSC C307331
C2, C13, C15: .1uF; C_0402_1005Metric; LCSC C1546
C3: 220pF; C_0402_1005Metric; LCSC C1530
C4: 0.47F; CP_Radial_D13.0mm_P5.00mm; LCSC C239004
C5, C7, C8, C9, C10, C11, C12, C14, C16, C17, C18: 10uF; C_0805_2012Metric; LCSC C15850
D1: LED; LED_0603_1608Metric; LCSC C2290
D2, D3, D4, D5, D6, D7, D8, D9: WS2812B; LED_WS2812B_PLCC4_5.0x5.0mm_P3.2mm
D10: 1N5819WS; D_SOD-323; LCSC C191023
EN_L: 5V_EN_L; TestPoint_Loop_D1.80mm_Drill1.0mm_Beaded
H1, H2, H3: MountingHole; MountingHole_3.2mm_M3
J4: USB_C_Receptacle_USB2.0; GCT_USB4120-03-C_REVA
MK1: CMM-4030D-261-I2S-TR; MIC_CMM-4030D-261-I2S-TR; PARTREV 1.0
Q1, Q5: AO4407C; SOIC-8_3.9x4.9mm_P1.27mm; LCSC C10491
Q2, Q6: AO3400A; SOT-23
R1, R11, R13, R17, R18: 1K; R_0402_1005Metric; LCSC C25744
R2: 220; R_0402_1005Metric; LCSC C25091
R3, R4: 5.1K; R_0402_1005Metric; LCSC C25905
R5: 220R; R_0402_1005Metric; LCSC C25091
R6: 10K; R_0603_1608Metric; LCSC C25804
R7, R8, R9: 51R; R_0603_1608Metric; LCSC C23197
R10, R19, R20: 10K; R_0402_1005Metric; LCSC C25744
R16, R21, R22, R23: 100K; R_0402_1005Metric; LCSC C25741
SW3: TL2233OA
U1: ESP32-WROOM-32D; ESP32-WROOM-32
U2: CH340C; SOIC-16_3.9x9.9mm_P1.27mm
U3: AMS1117-3.3; SOT-223-3_TabPin2
U4: LSM6DS33TR; PQFN50P300X300X86-16N; PARTREV 6
U5: LIS2DH; LGA-12_2x2mm_P0.5mm
U6: MH-CD42

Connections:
+3V3: C2.1, C3.1, C5.1, C6.1, C8.1, C13.1, C15.1, MK1.4 (CHIPEN), MK1.8 (VDD), R6.1, R10.2, R19.1, R20.1, U1.2 (VDD), U2.4 (V3), U2.16 (VCC), U3.2 (VO), U4.1 (VDDIO), U4.5 (CS), U4.16 (VDD), U5.2 (~CS), U5.9 (Vdd), U5.10 (Vdd_IO)
+5V: C7.1, C9.1, C10.1, C11.1, C12.1, C14.1, C16.1, C17.1, C18.1, D2.1 (VDD), D3.1 (VDD), D4.1 (VDD), D5.1 (VDD), D6.1 (VDD), D7.1 (VDD), D8.1 (VDD), D9.1 (VDD), D10.1 (K), Q1.1 (S), Q1.2 (S), Q1.3 (S), R11.1, U3.3 (VI), U6.1 (OUT-5V)
+BATT: +BAT.1, R16.1, U6.3 (BAT)
/5V_EN_L: EN_L.1, SW3.5 (B)
/BAT_VSENSE: R16.2, R21.1, U1.6 (IO34)
/BCLK: R8.2, U1.11 (IO26)
/CAP_VSENSE: R22.2, R23.1, U1.14 (IO12)
/CHARGE_CAP_EN: Q2.2 (G), R13.2, U1.12 (IO27)
/D+: J4.A6 (D+), J4.B6 (D+), U2.5 (UD+)
/D-: J4.A7 (D-), J4.B7 (D-), U2.6 (UD-)
/D_OUT_I2S: R9.1, U1.9 (IO33)
/FIRE_L: Q6.2 (G), R17.1, U1.13 (IO14)
/GPIO0: R2.1, R6.2, U1.25 (IO0)
/LED_SIG: D2.4 (DIN), U1.29 (IO5)
/RST: C1.1, R10.1, SW3.2 (B), U1.3 (EN), U2.14 (~RTS)
/RXD: U1.35 (TXD0/IO1), U2.3 (RXD)
/SCL: R20.2, U1.26 (IO4), U4.2 (SCL), U5.1 (SCL/SPC)
/SDA: R19.2, U1.27 (IO16), U4.3 (SDA), U5.4 (SDA/SDI)
/SHIELD: J4.S1 (SHIELD), Q5.5 (D), Q5.6 (D), Q5.7 (D), Q5.8 (D), R1.2
/TXD: U1.34 (RXD0/IO3), U2.2 (TXD)
/VBUS: D10.2 (A), J4.A4 (VBUS), J4.A9 (VBUS), J4.B4 (VBUS), J4.B9 (VBUS), U6.6 (VIN)
/WS: R7.2, U1.10 (IO25)
GND: C1.2, C2.2, C3.2, C4.2, C5.2, C6.2, C7.2, C8.2, C9.2, C10.2, C11.2, C12.2, C13.2, C14.2, C15.2, C16.2, C17.2, C18.2, D1.1 (K), D2.3 (VSS), D3.3 (VSS), D4.3 (VSS), D5.3 (VSS), D6.3 (VSS), D7.3 (VSS), D8.3 (VSS), D9.3 (VSS), J4.A1 (GND), J4.A12 (GND), J4.B1 (GND), J4.B12 (GND), MK1.1 (GND), MK1.5 (L/R), Q2.1 (S), Q6.1 (S), R1.1, R3.1, R4.2, R13.1, R21.2, R23.2, SW3.3 (C), SW3.4 (C), U1.1 (GND), U1.15 (GND), U1.38 (GND), U1.39 (GND), U2.1 (GND), U3.1 (GND), U4.4 (SDO/SA0), U4.8 (RES), U4.9 (RES), U4.10 (RES), U4.11 (RES), U4.12 (GND), U4.13 (GND), U4.15 (RES), U5.6 (GND), U5.7 (GND), U5.8 (GND), U6.2 (GND), U6.4 (GND), U6.5 (GND)
unnamed: C4.1, Q1.5 (D), Q1.6 (D), Q1.7 (D), Q1.8 (D), Q5.1 (S), Q5.2 (S), Q5.3 (S), R17.2, R18.1, R22.1
unnamed: D1.2 (A), R5.1
unnamed: D2.2 (DOUT), D3.4 (DIN)
unnamed: D3.2 (DOUT), D4.4 (DIN)
unnamed: D4.2 (DOUT), D5.4 (DIN)
unnamed: D5.2 (DOUT), D6.4 (DIN)
unnamed: D6.2 (DOUT), D7.4 (DIN)
unnamed: D7.2 (DOUT), D8.4 (DIN)
unnamed: D8.2 (DOUT), D9.4 (DIN)
unnamed: J4.A5 (CC1), R3.2
unnamed: J4.B5 (CC2), R4.1
unnamed: MK1.3 (WS), R7.1
unnamed: MK1.6 (SCK), R8.1
unnamed: MK1.7 (SD), R9.2
unnamed: Q1.4 (G), Q2.3 (D), R11.2
unnamed: Q5.4 (G), Q6.3 (D), R18.2
unnamed: R2.2, U2.13 (~DTR)
unnamed: R5.2, U1.16 (IO13)

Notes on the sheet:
3.3V regulated output for ESP
USB to Serial
ARGB LED Matrix
battery charge controller and 5V boost converter
MEMS Microphone
USB-C port
Filtering capacitors for LED matrix
ESP32
Accelerometer
Place accelerometer near mounting hole
Capacitor charge
capacitor discharge
SDO internally pulled up
SDO pulled down
ON/RESET BUTTON

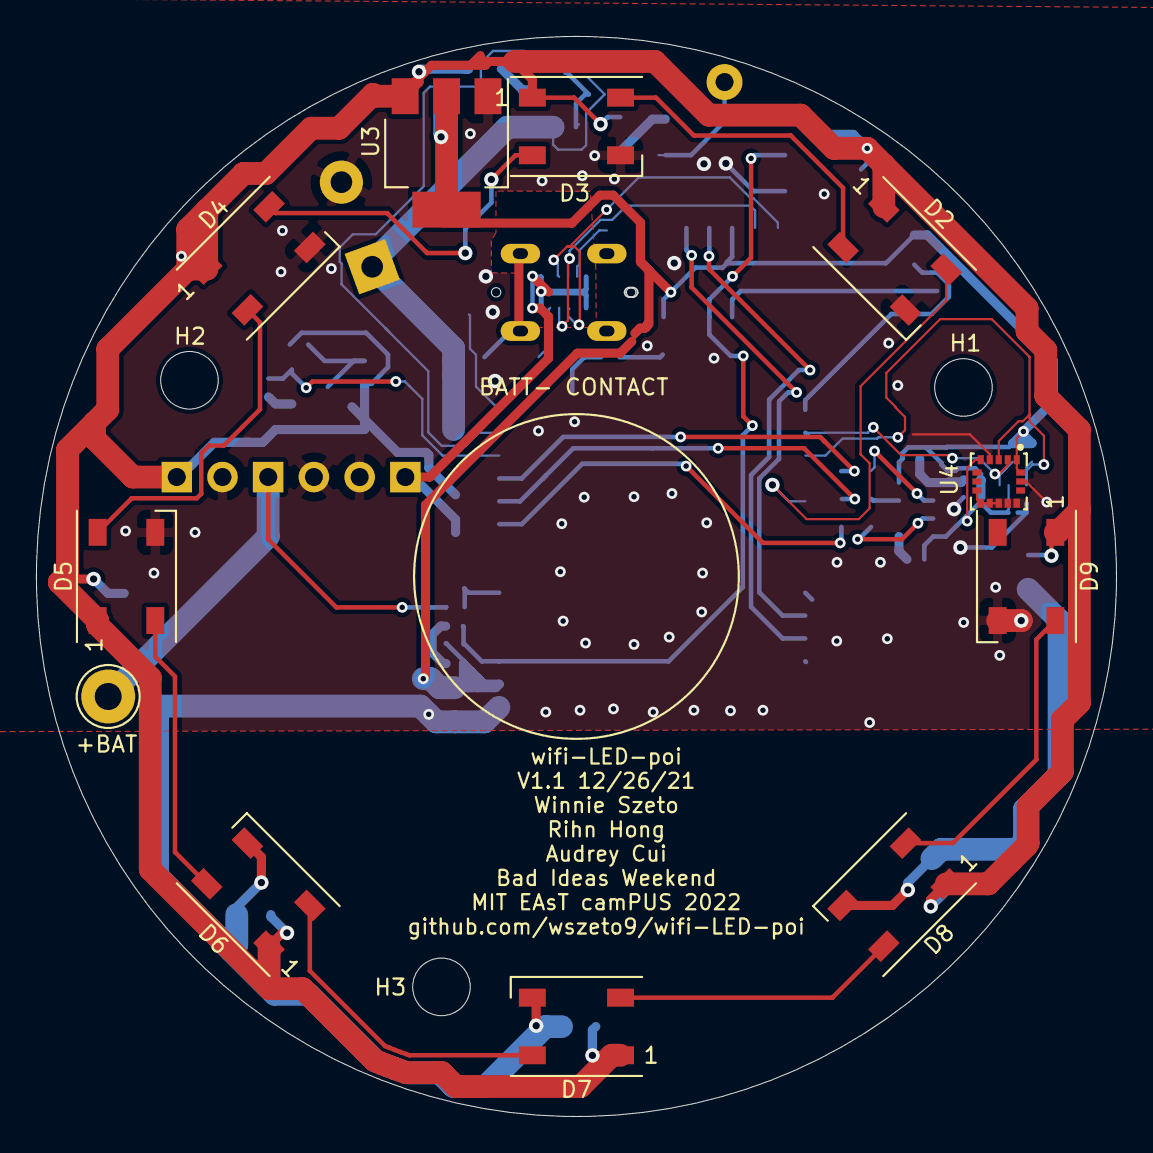
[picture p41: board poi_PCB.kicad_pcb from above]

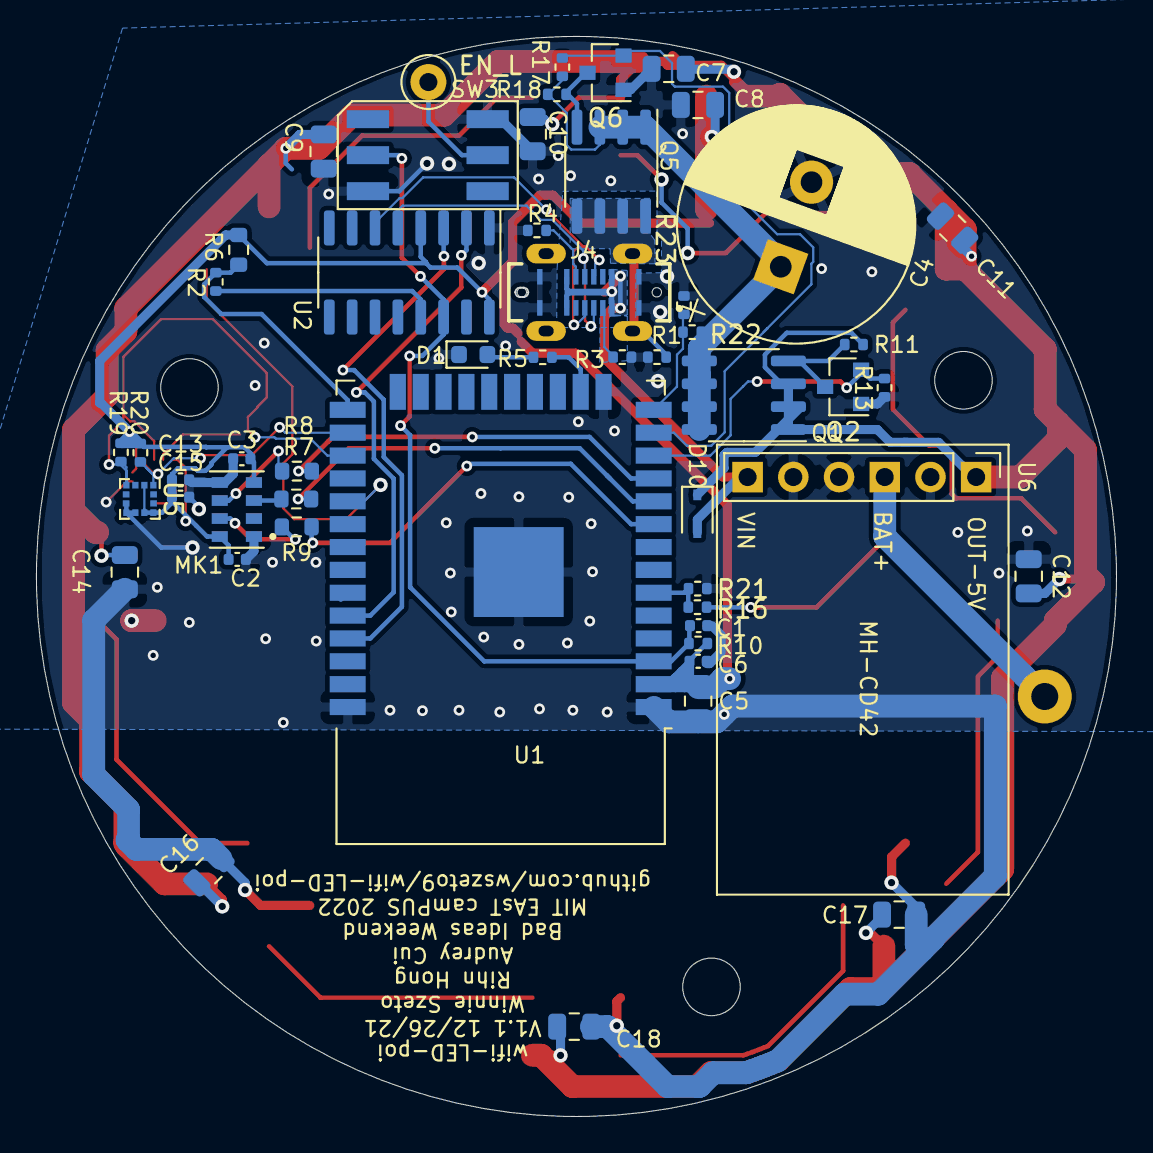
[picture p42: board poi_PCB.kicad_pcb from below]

Board: 2 copper layers, 60.0 x 60.0 mm, 66 parts (52 on the bottom side), 41 nets.

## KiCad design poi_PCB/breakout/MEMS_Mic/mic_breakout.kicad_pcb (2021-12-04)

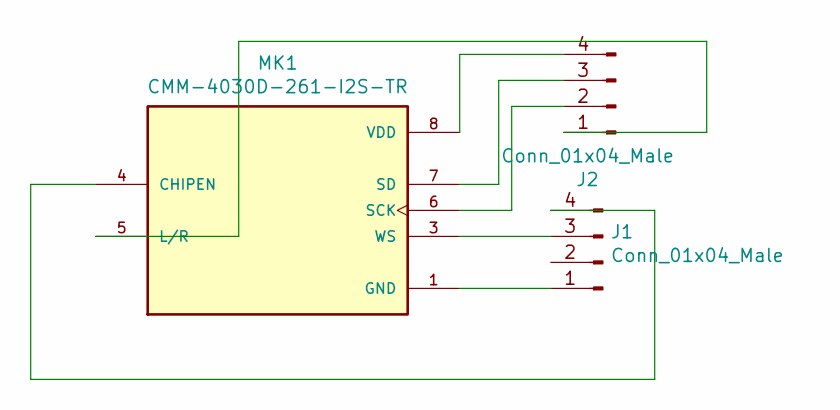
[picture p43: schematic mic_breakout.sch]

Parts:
J1, J2: Conn_01x04_Male; PinHeader_1x04_P2.54mm_Vertical
MK1: CMM-4030D-261-I2S-TR; MIC_CMM-4030D-261-I2S-TR; PARTREV 1.0

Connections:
unnamed: J1.1, MK1.1 (GND)
unnamed: J1.3, MK1.3 (WS)
unnamed: J1.4, MK1.4 (CHIPEN)
unnamed: J2.1, MK1.5 (L/R)
unnamed: J2.2, MK1.6 (SCK)
unnamed: J2.3, MK1.7 (SD)
unnamed: J2.4, MK1.8 (VDD)

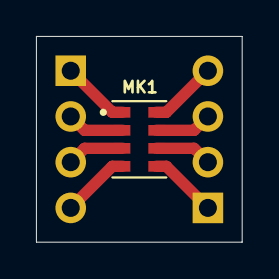
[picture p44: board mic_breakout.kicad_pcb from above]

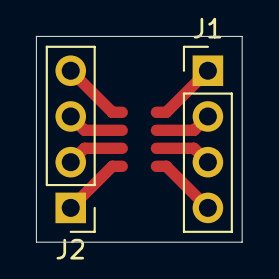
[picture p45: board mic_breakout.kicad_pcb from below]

Board: 2 copper layers, 11.4 x 11.4 mm, 3 parts (2 on the bottom side), 7 nets.

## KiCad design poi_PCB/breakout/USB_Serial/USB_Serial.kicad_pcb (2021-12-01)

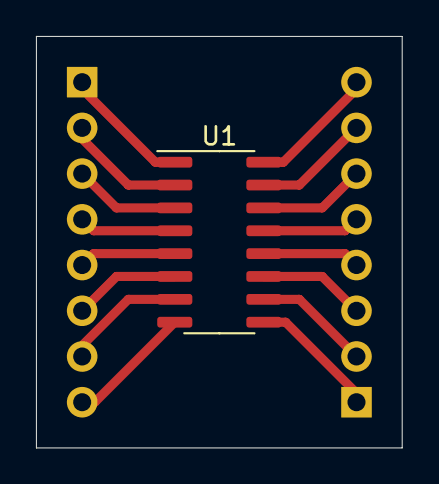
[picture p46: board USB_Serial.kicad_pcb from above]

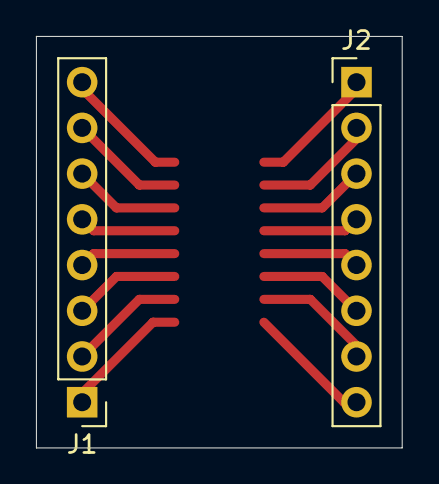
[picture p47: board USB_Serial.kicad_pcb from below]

Board: 2 copper layers, 20.3 x 22.9 mm, 3 parts (2 on the bottom side), 16 nets.

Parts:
J1, J2: Conn_01x08_Female; PinHeader_1x08_P2.54mm_Vertical
U1: CH340G; SOIC-16_3.9x9.9mm_P1.27mm

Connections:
unnamed: J1.1, U1.9
unnamed: J1.2, U1.10
unnamed: J1.3, U1.11
unnamed: J1.4, U1.12
unnamed: J1.5, U1.13
unnamed: J1.6, U1.14
unnamed: J1.7, U1.15
unnamed: J1.8, U1.16
unnamed: J2.1, U1.1
unnamed: J2.2, U1.2
unnamed: J2.3, U1.3
unnamed: J2.4, U1.4
unnamed: J2.5, U1.5
unnamed: J2.6, U1.6
unnamed: J2.7, U1.7
unnamed: J2.8, U1.8

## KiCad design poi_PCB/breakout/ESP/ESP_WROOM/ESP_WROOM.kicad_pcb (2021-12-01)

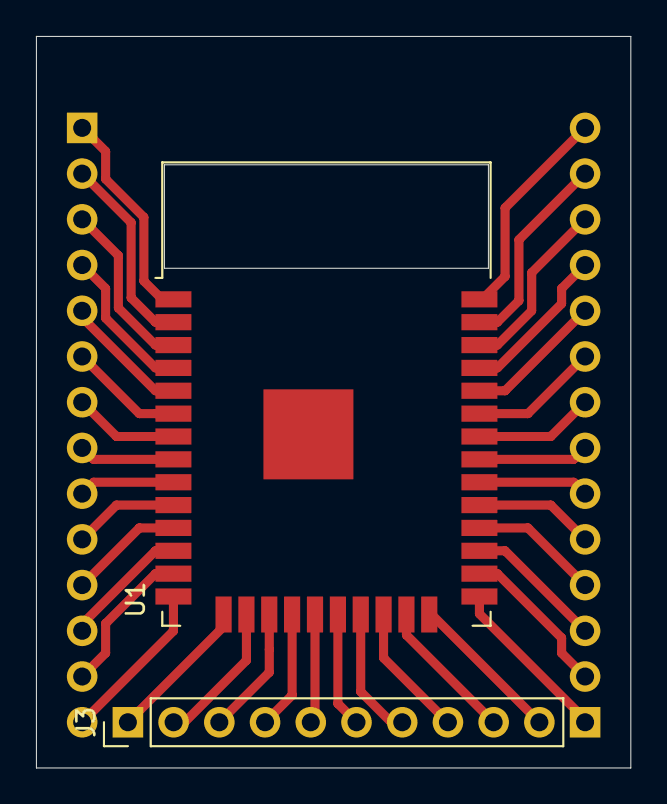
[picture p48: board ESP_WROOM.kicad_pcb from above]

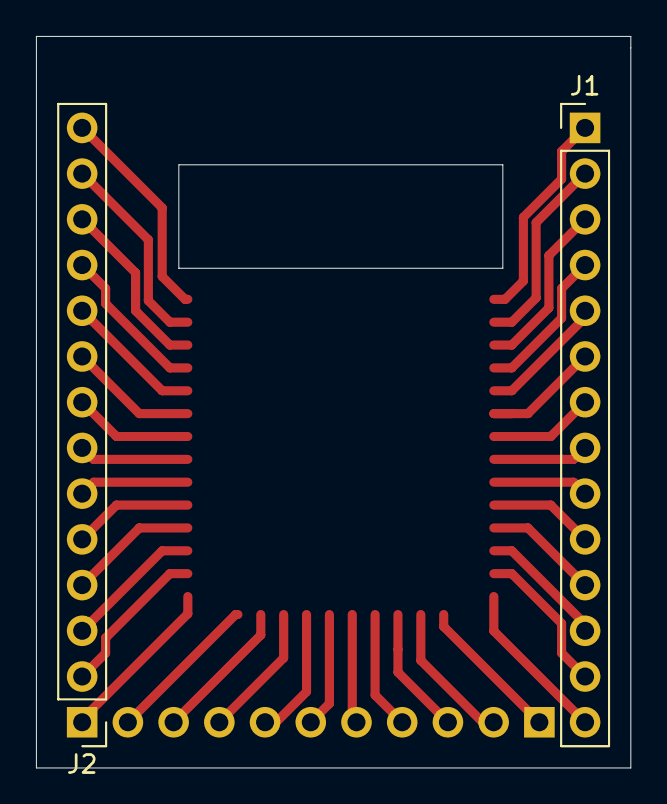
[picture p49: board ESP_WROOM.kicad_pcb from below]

Board: 2 copper layers, 33.0 x 40.6 mm, 4 parts (2 on the bottom side), 35 nets.

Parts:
J1, J2: Conn_01x14_Female; PinHeader_1x14_P2.54mm_Vertical
J3: Conn_01x10_Female; PinHeader_1x10_P2.54mm_Vertical
U1: ESP32-WROOM-32D; ESP32-WROOM-32

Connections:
/1: J1.1, J2.14, J3.1, U1.1, U1.15, U1.38, U1.39
/2: J1.2, U1.2
/3: J1.3, U1.3
/4: J1.4, U1.4
/5: J1.5, U1.5
/6: J1.6, U1.6
/7: J1.7, U1.7
/8: J1.8, U1.8
/9: J1.9, U1.9
/10: J1.10, U1.10
/11: J1.11, U1.11
/12: J1.12, U1.12
/13: J1.13, U1.13
/14: J1.14, U1.14
/16: J3.2, U1.16
/17: J3.3, U1.17
/18: J3.4, U1.18
/19: J3.5, U1.19
/20: J3.6, U1.20
/21: J3.7, U1.21
/22: J3.8, U1.22
/23: J3.9, U1.23
/24: J3.10, U1.24
/25: J2.1, U1.25
/26: J2.2, U1.26
/27: J2.3, U1.27
/28: J2.4, U1.28
/29: J2.5, U1.29
/30: J2.6, U1.30
/31: J2.7, U1.31
/33: J2.9, U1.33
/34: J2.10, U1.34
/35: J2.11, U1.35
/36: J2.12, U1.36
/37: J2.13, U1.37

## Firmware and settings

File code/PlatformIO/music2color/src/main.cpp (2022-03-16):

#include <Arduino.h>
#include <WiFi.h>
#include <FastLED.h>
#include <string.h>
#include "SparkFun_LIS2DH12.h" 
#include <Wire.h>
#include <analogWrite.h>

SPARKFUN_LIS2DH12 accel;

//LED init
#define LED_BUILTIN  13
#define LED_ARRAY 17
#define NUM_LEDS    8 
#define PATTERN_LEN 1
#define BRIGHTNESS  255
CRGB leds[NUM_LEDS];
String rgbState = "000000000";
// CRGB current_color = CRGB(100, 0, 0); 

//wifi init
const char* ssid = "winnie";
const char* password = "allisonswifisucks";
// Set web server port number to 80
WiFiServer server(80);


// Variable to store the HTTP request
String header;

// Current time
unsigned long currentTime = millis();
// Previous time
unsigned long previousTime = 0; 
// Define timeout time in milliseconds (example: 2000ms = 2s)
const long timeoutTime = 2000;

/* Setting PWM Properties for LED power indicator */
int dutyCycle;
float battery_voltage;
const int PWMFreq = 1; 
const int PWMChannel = 0;
const int PWMResolution = 8;
const int MAX_DUTY_CYCLE = (int)(pow(2, PWMResolution) - 1);

float brightness_coeff = 1;
  int r = 100;
  int g = 0;
  int b = 0;

String charge_state = "off"; 
String discharge_state = "off"; 
int CHARGE_OUTPUT = 27; 
int DISCHARGE_OUTPUT = 14; 
const int CHARGE_INPUT = 12; 
const int INCREASE_RATE = 5; 
const int CHARGE_DELAY_TIME = 100; 
int charge_duty_cycle = 1; 
unsigned long charge_prev_increase = millis(); 
unsigned long charge_current_time = millis(); 

void setup() {
  battery_voltage = (float) analogRead(34) / 4095 * 3.3 * 2;
  ledcSetup(PWMChannel, PWMFreq, PWMResolution);
  ledcAttachPin(LED_BUILTIN, PWMChannel);
  ledcWrite(PWMChannel, MAX_DUTY_CYCLE * (battery_voltage-3.0) / (4.2-3.0));

  pinMode(LED_BUILTIN, OUTPUT); 
  pinMode(CHARGE_OUTPUT, OUTPUT); 
  pinMode(DISCHARGE_OUTPUT, OUTPUT); 
  digitalWrite(CHARGE_OUTPUT, LOW); 
  digitalWrite(DISCHARGE_OUTPUT, LOW); 

  FastLED.addLeds<NEOPIXEL, LED_ARRAY>(leds, NUM_LEDS);
  
  // set the LED brightness
  FastLED.setBrightness(BRIGHTNESS);

  fill_solid(leds, NUM_LEDS, CRGB(r, g, b));
  FastLED.show();

  delay( 3000 ); // power-up safety delay
  Serial.begin(115200);
  //Serial.print("HERE");
  // Connect to Wi-Fi network with SSID and password

 // if (!WiFi.config(local_IP, gateway, subnet)) {
 //   Serial.println("STA Failed to configure");
 // }

 Wire.begin(16,4);

 if (accel.begin() == false)
  {
    Serial.println("Accelerometer not detected");
  }
  accel.setScale(LIS2DH12_16g);
  accel.setDataRate(LIS2DH12_ODR_200Hz);
  accel.setMode(LIS2DH12_NM_10bit);

  Serial.print("Connecting to ");
  Serial.println(ssid);
  WiFi.begin(ssid, password);
  
  while (WiFi.status() != WL_CONNECTED) {
    delay(500);
    Serial.print(".");
  }
  // Print local IP address and start web server

  //current_color = CRGB(0, 100, 0);
  r = 0; 
  g = 100; 
  b = 0;
  fill_solid(leds, NUM_LEDS, CRGB(r, g, b));
  FastLED.show();

  Serial.println("");
  Serial.println("WiFi connected.");
  Serial.println("IP address: ");
  Serial.println(WiFi.localIP());
  server.begin();


}

void loop() {

//set brightness coeff based on accel readings
if (accel.available())
  {
    float accelX = accel.getX()/1000;
    float accelY = accel.getY()/1000;
    float accelZ = accel.getZ()/1000;
    float accel_mag = sqrt(accelX * accelX + accelY * accelY + accelZ * accelZ);
    brightness_coeff = (float)0.5/(accel_mag-0.5);
  }

  float capacitor_voltage = (float) analogRead(CHARGE_INPUT) / 4095 * 3.3 * 2;

  // put your main code here, to run repeatedly:
  WiFiClient client = server.available();   // Listen for incoming clients

  if (client) {                             // If a new client connects,
    currentTime = millis();
    previousTime = currentTime;
    Serial.println("New Client.");          // print a message out in the serial port
    String currentLine = "";                // make a String to hold incoming data from the client
    while (client.connected() && currentTime - previousTime <= timeoutTime) {  // loop while the client's connected
      currentTime = millis();
      if (client.available()) {             // if there's bytes to read from the client,
        char c = client.read();             // read a byte, then
        Serial.write(c);                    // print it out the serial monitor
        header += c;
        if (c == '\n') {                    // if the byte is a newline character
          // if the current line is blank, you got two newline characters in a row.
          // that's the end of the client HTTP request, so send a response:
          if (currentLine.length() == 0) {
            // HTTP headers always start with a response code (e.g. HTTP/1.1 200 OK)
            // and a content-type so the client knows what's coming, then a blank line:
            client.println("HTTP/1.1 200 OK");
            client.println("Content-type:text/html");
            client.println("Connection: close");
            client.println();

            if (header.indexOf("GET /" + String(CHARGE_OUTPUT) + "/on") >= 0) {
              Serial.println("charging");
              charge_state = "on";
              //digitalWrite(CHARGE_OUTPUT, HIGH);
              // charge_current_time = millis(); 
              // if (charge_duty_cycle <= 250 && charge_current_time >= CHARGE_DELAY_TIME){
              //   charge_duty_cycle += INCREASE_RATE;
              //   Serial.print(charge_duty_cycle);  
              // }
              // analogWrite(LED_BUILTIN, charge_duty_cycle); 
            } else if (header.indexOf("GET /" + String(CHARGE_OUTPUT) + "/off") >= 0) {
              Serial.println("not charging");
              charge_state = "off";
              digitalWrite(CHARGE_OUTPUT, LOW);
            } else if (header.indexOf("GET /" + String(DISCHARGE_OUTPUT) + "/on") >= 0) {
              Serial.println("discharging");
              discharge_state = "on";
              charge_state = "off"; 
              digitalWrite(DISCHARGE_OUTPUT, HIGH);
            } else if (header.indexOf("GET /" + String(DISCHARGE_OUTPUT) + "/off") >= 0) {
              Serial.println("not discharging");
              discharge_state = "off";
              digitalWrite(DISCHARGE_OUTPUT, LOW);
            }
 
            // Display the HTML web page
            client.println("<!DOCTYPE html><html>");
            client.println("<head><meta name=\"viewport\" content=\"width=device-width, initial-scale=1\">");
            client.println("<link rel=\"icon\" href=\"data:,\">");
            // CSS to style the on/off buttons 
            // Feel free to change the background-color and font-size attributes to fit your preferences
            client.println("<style>html { font-family: Helvetica; display: inline-block; margin: 0px auto; text-align: center;}");
            client.println(".button { background-color: #4CAF50; border: none; color: white; padding: 16px 40px;");
            client.println("text-decoration: none; font-size: 30px; margin: 2px; cursor: pointer;}");
            client.println(".button2 {background-color: #555555;}</style></head>");
 
            // Web Page Heading
            client.println("<body><h1>ESP32 Web Server</h1>");
 
            // Display current state, and ON/OFF buttons for GPIO 26  
            client.println("<p>Charging - State " + charge_state + "</p>");
            // If the output26State is off, it displays the ON button       
            if (charge_state=="off") {
              client.println("<p><a href=\"/" + String(CHARGE_OUTPUT) + "/on\"><button class=\"button\">ON</button></a></p>");
            } else {
              client.println("<p><a href=\"/" + String(CHARGE_OUTPUT) + "/off\"><button class=\"button button2\">OFF</button></a></p>");
            } 
 
            // Display current state, and ON/OFF buttons for GPIO 27  
            client.println("<p>Discharging - State " + discharge_state + "</p>");
            // If the output27State is off, it displays the ON button       
            if (discharge_state == "off") {
              client.println("<p><a href=\"/" + String(DISCHARGE_OUTPUT) + "/on\"><button class=\"button\">ON</button></a></p>");
            } else {
              client.println("<p><a href=\"/" + String(DISCHARGE_OUTPUT) + "/off\"><button class=\"button button2\">OFF</button></a></p>");
            }

            client.println("<p>capacitor voltage: " + String(capacitor_voltage) + "</p>"); 
            client.println("</body></html>");
            
            //Serial.println(header); 
            if (header.indexOf("GET /" + String(LED_ARRAY)) >= 0)
            {
              String color_string = header.substring(8, 17);
              Serial.println(color_string);
              if (color_string.toInt() > 0) 
              {
                r = color_string.substring(0, 3).toInt(); 
                g = color_string.substring(3, 6).toInt(); 
                b = color_string.substring(6, 9).toInt(); 
              }
        
            }
            
            // The HTTP response ends with another blank line
            client.println();
            // Break out of the while loop
            break;
          } else { // if you got a newline, then clear currentLine
            currentLine = "";
          }
        } else if (c != '\r') {  // if you got anything else but a carriage return character,
          currentLine += c;      // add it to the end of the currentLine
        }
      }
    }
    // Clear the header variable
    header = "";
    // Close the connection
    client.stop();
    Serial.println("Client disconnected.");
    Serial.println("");
    delay(1000);
  }

  if (charge_state == "on")
  {
    charge_current_time = millis(); 
    if (charge_duty_cycle <= 250 && charge_current_time >= CHARGE_DELAY_TIME){
      charge_duty_cycle += INCREASE_RATE;
      Serial.print(charge_duty_cycle);  
    }
    analogWrite(CHARGE_OUTPUT, charge_duty_cycle); 

    
  }
  //testing
  if (!accel.available()){
    brightness_coeff = 1; 
  }
  else brightness_coeff = constrain(brightness_coeff, 0.1, 2); 
  //brightness_coeff = 1; 
  int r_adj = constrain((int)r * brightness_coeff, 0, 255);
  int g_adj = constrain((int)g * brightness_coeff, 0, 255);
  int b_adj = constrain((int)b * brightness_coeff, 0, 255);
  
  char buffer[50];
  //sprintf (buffer, "%r: %d, %d, g: %d, %d, b: %d, %d, coeff: %f",r, r_adj, g, g_adj, b, b_adj, brightness_coeff);
  //Serial.println (buffer);
  fill_solid(leds, NUM_LEDS, CRGB(r_adj, g_adj, b_adj));
  FastLED.show();
  delay(100);
}

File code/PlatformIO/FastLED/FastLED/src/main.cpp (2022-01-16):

#include <FastLED.h>

// How many leds in your strip?
#define NUM_LEDS 8 

// For led chips like Neopixels, which have a data line, ground, and power, you just
// need to define DATA_PIN.  For led chipsets that are SPI based (four wires - data, clock,
// ground, and power), like the LPD8806, define both DATA_PIN and CLOCK_PIN
#define DATA_PIN 5
//#define CLOCK_PIN 13

// Define the array of leds
CRGB leds[NUM_LEDS];

void setup() { 
	pinMode(34, INPUT);
	Serial.begin(115200);
	Serial.println("resetting");
	LEDS.addLeds<WS2812,DATA_PIN,RGB>(leds,NUM_LEDS);
	LEDS.setBrightness(255);
}

void fadeall() { for(int i = 0; i < NUM_LEDS; i++) { leds[i].nscale8(250); } }

void loop() { 
	static uint8_t hue = 0;
	Serial.println(analogRead(34) / 4095 * 3.3 * 2);
	// First slide the led in one direction
	for(int i = 0; i < NUM_LEDS; i++) {
		// Set the i'th led to red 
		leds[i] = CHSV(hue++, 255, 255);
		// Show the leds
		FastLED.show(); 
		// now that we've shown the leds, reset the i'th led to black
		// leds[i] = CRGB::Black;
		fadeall();
		// Wait a little bit before we loop around and do it again
		delay(10);
	}


	// Now go in the other direction.  
	for(int i = (NUM_LEDS)-1; i >= 0; i--) {
		// Set the i'th led to red 
		leds[i] = CHSV(hue++, 255, 255);
		// Show the leds
		FastLED.show();
		// now that we've shown the leds, reset the i'th led to black
		// leds[i] = CRGB::Black;
		fadeall();
		// Wait a little bit before we loop around and do it again
		delay(10);
	}
}

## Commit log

2021-11-14 Initial upload
    Created schematic of board
    [PD_Micro.kicad_pcb, PD_Micro.sch, poi_PCB.kicad_pcb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]
2021-11-14 deleted unused files
    [PD_Micro.kicad_pcb, PD_Micro.sch]
2021-11-23 added TP4056 footprint
    [poi_PCB.sch]
2021-11-25 Changed USB-> Serial chip, added documentation
    -CH340G replaced with CH340C to eliminate the need for a crystal
    -Part sourcing updated in BOM
    -minor edits based on available parts
    -Schematic updated to reflect changes
    [LatchSwitch_7x7.STEP, USB4120-03-C_REVA.step, poi_PCB.kicad_pcb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]
2021-11-25 PCB changed to white solder mask, added STEP files
2021-11-25 Added full assembly renders
    Checked to see how LEDs would diffuse with a battery in the center
2021-11-26 Added mounting holes
    [SPH0645LM4H-B.step, poi_PCB.kicad_pcb, poi_PCB.sch]
2021-12-01 Verified reset circuit
    Breadboarded and edited reset circuit.
    -USBC port moved closer to center
    -transistors replaced because of issues with transistor quality
    [ESP_WROOM.kicad_pcb, ESP_WROOM.sch, USB_Serial.kicad_pcb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]
2021-12-03 added code and calculations for accelerometer
2021-12-04 redone traces, changed accelerometer, supercapacitor and mic
    [CUI_DEVICES_CMM-4030D-261-I2S-TR.step, LSM6DS33TR.step, TL2233OA.step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]
2021-12-05 Verified pinouts
    -Pinouts all checked to be compatible with peripherals.
    -FIRE is pulled up to +CAP, and drains within 20 minutes if the device is turned off
    [MH-CD42.step, poi_PCB.kicad_pcb, poi_PCB.sch]
2021-12-05 updated sourcing info
    [poi_PCB.kicad_pcb]
2021-12-06 Updated pictures and schematics, added analog RGB header
    analog RGB header is designed for 12V analog RGB strips
    [poi_PCB.kicad_pcb, poi_PCB.sch]
2021-12-06 Added fabrication files
    [poi_PCB-B_Cu.gbr, poi_PCB-B_Mask.gbr, poi_PCB-B_Paste.gbr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]
2021-12-11 added manufacturing files
    [PCB_scale_model.3mf, PCB_shield_waterjet_template.dxf, PCB_spacer.3mf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]
2021-12-25 Update LSM6_serial.ino
    Changed pinout of LSM6 to reflect PCB
2021-12-25 Added mechanical assembly files
2021-12-26 Changed schematic based on testing
    -LED logic level shifter omitted due to slow switching speed of AO3400A
    -LED input moved to GPIO5 to avoid pulling up GPIO2 during UART programming
    -Gate pullup/pulldown resistors changed to 1K to allow for faster switching
    -analog RGB header omitted
    [poi_PCB.kicad_pcb, poi_PCB.sch]
2021-12-26 Added FastLED library via PlatformIO
    Switching programming platform to PlatformIO because FastLED does not work in the Arduino IDE.
    [main.cpp]
2021-12-26 added microphone test code
    changes LED brightness based on volume
2021-12-27 added WLED source code
    [IR_Remote_Codes.xlsx, WLED_ESP32_16MB.csv, WLED_ESP32_4MB_1MB_FS.csv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]
2021-12-27 Added mold specific files
    [mold_assembly.step]
2021-12-27 reorganized file folders
    [PCB_shield_waterjet_template.dxf, PCB_spacer.3mf, [OPTIONAL]PCB_scale_model.3mf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]
2022-01-02 added example code
    blinks LED, speed varies with acceleration data measured. faster acceleration leads to faster blinks
2022-01-02 Updated 3D files
    [inside-top_piece.3mf, mold_bottom_outer.3mf, mold_inside_piece_A.3mf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]
2022-01-03 Update mold assembly.pdf
2022-01-03 updated assembly video to reflect recent edits
2022-01-03 added tolerances to mold
    [mold_assembly.step]
2022-01-03 changed height of hole to reflect bridging tolerances in 3d printing
    [mold_inside_piece_A.3mf]
2022-01-15 pump up brightness
2022-01-17 Added accelerometer
    -Added accelerometer code to vary brightness based on accel
    -LED indicator at the bottom changes PWM cycle based on battery charge
2022-01-20 added charge/discharge
